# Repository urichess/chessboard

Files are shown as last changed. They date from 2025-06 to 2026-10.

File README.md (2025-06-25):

# chessboard

tests of chessboard using arduino + zephyr

Start up

1. install zephyr

https://docs.zephyrproject.org/latest/develop/getting_started/index.html

2. install Stm32CubeIDE & Stm32CubeProgrammer

3. clone this repo

4. (optionl) configure cubeide
https://docs.zephyrproject.org/latest/develop/tools/stm32cubeide.html

Interesting links

Proyectos y tecnologías clave que te pueden ayudar
1. lichess-bot

https://github.com/lichess-bot-devs/lichess-bot

Un bot que se conecta a la API de Lichess y puede jugar partidas automáticamente.

Puedes modificarlo para que, en lugar de usar un motor de ajedrez, se comunique con tu hardware.

Es ideal como punto de partida para jugar partidas en Lichess a través de tu propio programa.

2. PySerial

https://pyserial.readthedocs.io/en/latest/pyserial.html#overview
Para comunicarte con tu tablero por USB (si usas un puerto serie virtual tipo /dev/ttyUSB0).

Puedes leer movimientos desde tu tablero y enviarle información como el movimiento del oponente.

3. Python-Chess
https://python-chess.readthedocs.io/en/latest/#
Excelente librería para manejar lógica de ajedrez (validar jugadas, FENs, PGNs).

Puedes usarla para comparar el estado del juego local con el de Lichess y traducir movimientos.

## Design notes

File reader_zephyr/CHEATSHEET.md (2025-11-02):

#INIT ENV
. ./scripts/activate

#COMPILE

./scripts/build_all.sh [-clean]

#ZEPHYR COMMANDS TO COMPILE

west build -p always -b arduino_uno_r4_wifi

west build -p always -b nucleo_g474re
west build -p auto -b nucleo_g474re
west build -p always -b nucleo_g474re -t dt

#CONFIG

west build -b chessboard_l431_v1 -t menuconfig app

#UTILS
west boards

#UPGRADING

cd  $ZEPHYR_BASE
git pull
west update
west packages pip --install

python -m serial.tools.miniterm /dev/ttyACM0 115200
west build -b chessboard_l431_v1  -d build/mcuboot/ -p auto  bootloader/mcuboot/boot/zephyr/ -t menuconfig --extra-conf /home/elotro/work/chessApps/chessboard/reader_zephyr/bootloader/config_overrides.conf

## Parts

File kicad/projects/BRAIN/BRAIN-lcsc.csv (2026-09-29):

Reference | Value | Qty | MP | LCSC p/n
J1 | USB_C_Receptacle_USB2.0_16P | 1 | XKB Connection U262-161N-4BS165 | C2879826
J15 | CONN_2x03 | 1 | XFCN PZ254V-12-6P | C492421
J11 | CONN_1x14 | 1 | X6511FV-14-C85D32 | C2883731
D3 | TVS3V3L4U | 1 | TVS3V3L4U | C28642315
SW1,SW2,SW3 | TL3342F450QG | 3 | TL3342F450QG | C318884
D8,D9 | SS14 | 2 | SS14-E3/61T | C47460
R2,R3,R4,R6,R8,R9,R12 | 5.1k | 7 | RC0805FR-075K1L | C84375
R15 | 47k | 1 | RC0805FR-0747KL | C126351
R1,R13,R14 | 10k | 3 | RC0805FR-0710KL | C84376
R7 | 1k | 1 | RC0805FR-071KL | C95781
J16 | CONN_2x04 | 1 | PZ254V-12-8P | C492421
J18 | Free | 1 | PZ254V-11-04P | C2691448
J14 | UART | 1 | PZ254V-11-04P | C2691448
D7 | PESD5V0L2BT | 1 | PESD5V0L2BT,215 | C12324
Y1 | NX3215SA-32.768KHZ-EXS00A-MU00525 | 1 | NX3215SA 32.768KHZ EXS00A-MU00525 | C528987 | C5142784
D1,D2,D6 | LED_GREEN | 3 | L170B-YGC-GA-TR | C84260
D5 | LED_ORANGE | 1 | L170B-QOC-TR | C965817
D4 | LED_RED | 1 | L170B-EC-TR | C84256
J12 | CONN_2x02 | 1 | JST RF-H042TD-1190(LF)(SN) | C160338
U7 | ESP32-S3-MINI-1-N8 | 1 | ESP32-S3-MINI-1-N8 | C2913206
J9 | CONN_01x02 | 1 | DW254R-11-02-85 | C2935896
C7,C10 | 4.7pF | 2 | CL21C470JBANNNC | C1820
C4 | 22pF | 1 | CL21C220JBANNNC | C1804
C1,C5,C6,C9,C13,C14 | 100nF | 6 | CL21B104KBCNNNC | C1711
C8,C11,C12,C15,C16 | 1uF | 5 | CL21A105KOFNNNE | C24123 | FALTA
J2,J4 | Conn_ARM_JTAG_SWD_10 | 2 | BD125-16-A-0305-0580-L-B | C17283499 | FALTA
Q2 | BC847 | 1 | BC847B,215 | C57668
J10 | CONN_2x1 | 1 | B2B-EH-A(LF)(SN) | C160262
U1,U3 | AP2112K-3.3 | 2 | AP2112K-3.3TRG1 | C23380830
C2,C3 | 3.9pF | 2 | 0805CG3R9C500NT | C1813
J13 | UART TEST | 1 | 22284020 | C234182
R16,R17,R18,R19 | 100 | 4 |  | C17408
J8 | Conn_02x11_Odd_Even | 1 |  |  | FALTA
J3,J5,J6,J7 | Conn_01x07 | 4 |  |  | FALTA
C17,C18,C19,C20 | 1uF | 4 |  | C28323
REEMPLAZADO
U2 | STM32L431CCTx | 1 | STM32L431CCTx | C486681
TUOMO
NO COMPRADO
LS1 | CMT-1203-SMT | 1 | CMT-1203-SMT-TR |  | FALTA
U4 | 24LC512 | 1 | 24LC512T-I/SN | C52088 | FALTA

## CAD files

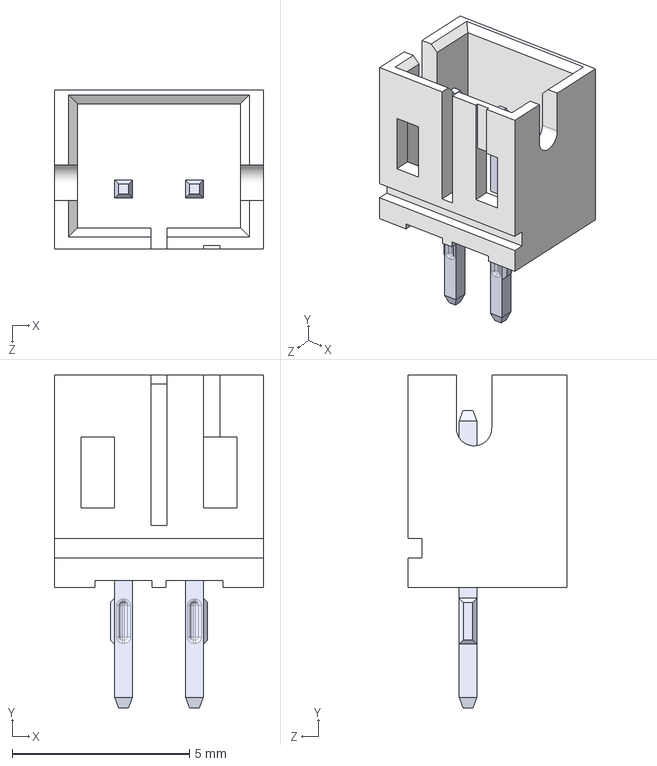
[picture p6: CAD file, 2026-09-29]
kicad/MY_PARTS/B2B-PH-K-S_LF__SN_/B2B-PH-K-S_LF__SN_.step
5.90 x 9.40 x 4.50 mm

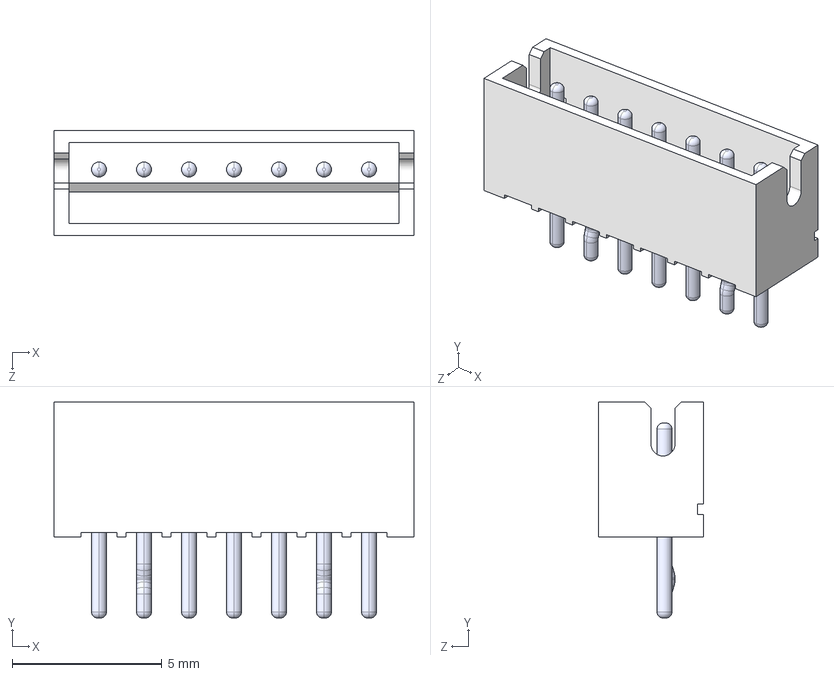
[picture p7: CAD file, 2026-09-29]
kicad/MY_PARTS/B7B-ZR_LF__SN_/B7B-ZR_LF__SN_.step
12.0 x 7.20 x 3.50 mm
BxB-ZR_7
pin_straight x 5
pin_Bent x 2

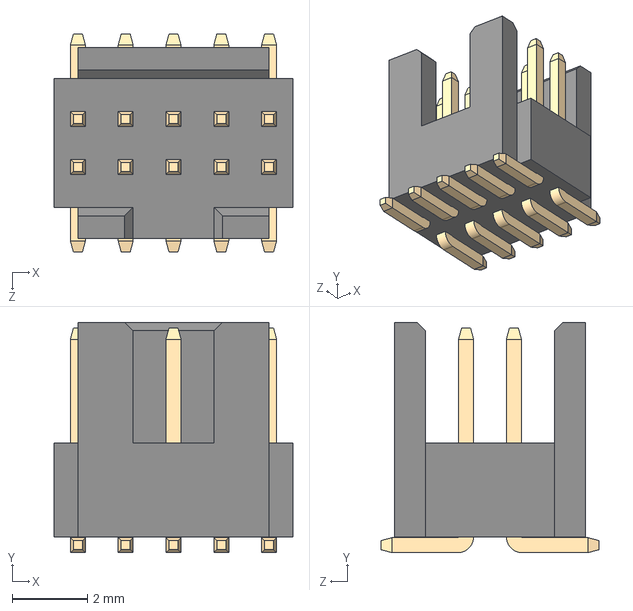
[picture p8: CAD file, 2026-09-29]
kicad/MY_PARTS/BD125-10-A-0305-0580-L-B/BD125-10-A-0305-0580-L-B.step
6.35 x 6.12 x 5.80 mm

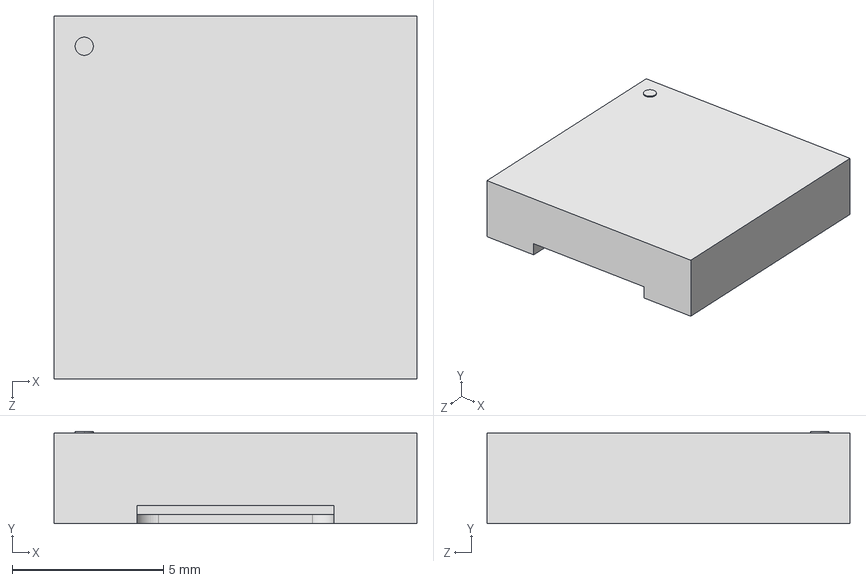
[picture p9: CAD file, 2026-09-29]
kicad/MY_PARTS/CMT-1203-SMT/CMT-1203-SMT.step
12.0 x 3.05 x 12.0 mm

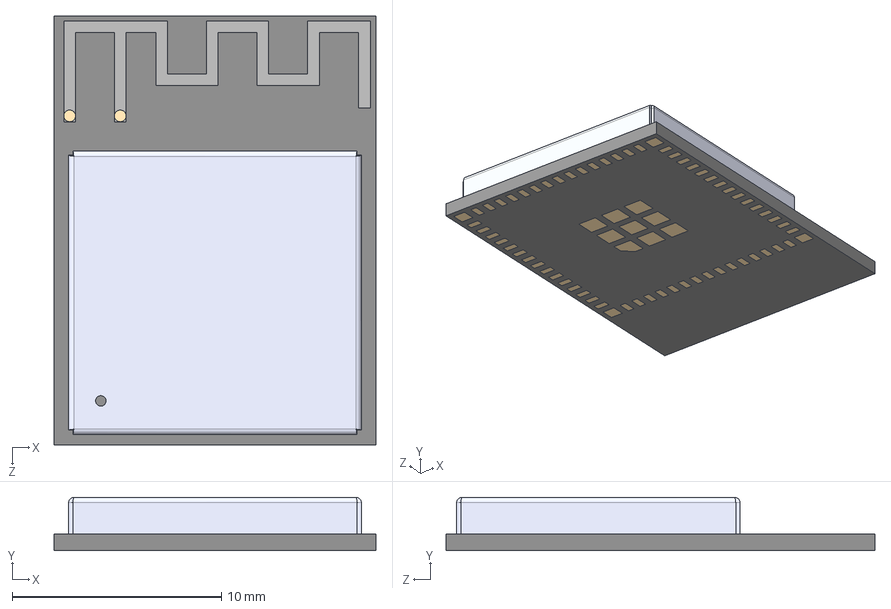
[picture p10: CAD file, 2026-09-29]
kicad/MY_PARTS/ESP32-S3-MINI-1-N8/ESP32-S3-MINI-1-N8.step
15.4 x 2.55 x 20.5 mm

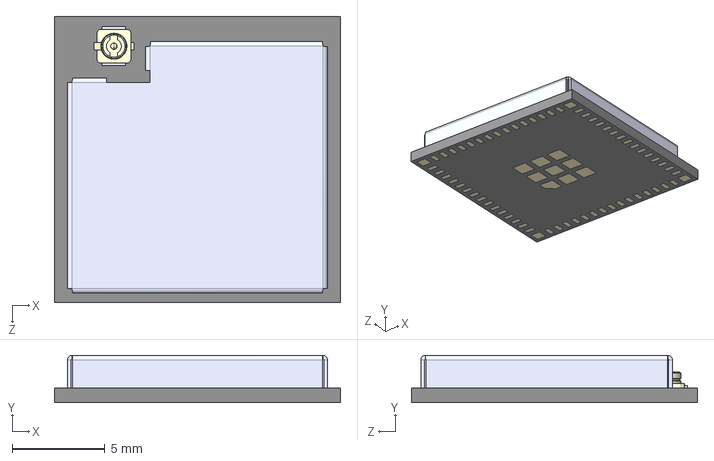
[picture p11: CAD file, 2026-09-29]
kicad/MY_PARTS/ESP32-S3-MINI-1U-N8/ESP32-S3-MINI-1U-N8.step
15.4 x 2.55 x 15.4 mm
ESP32-S3-MINI-1U-N8_ESP32-C3-MINI-1-N4
antenna jack

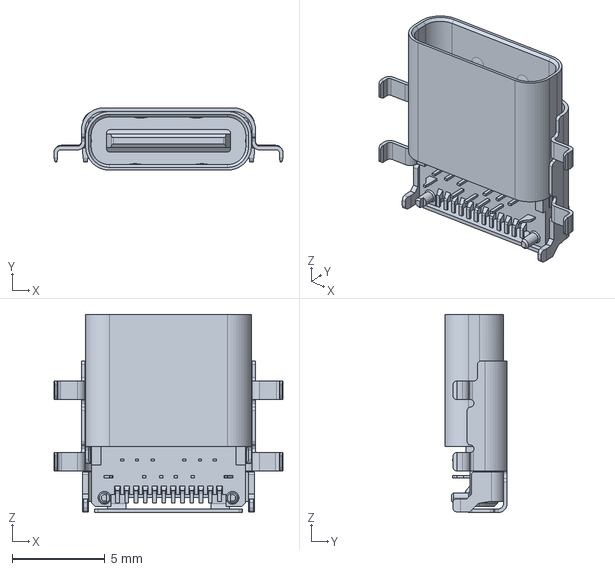
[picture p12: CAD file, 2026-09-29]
kicad/MY_PARTS/2129691-2/2129691-2.step
12.4 x 3.36 x 10.7 mm

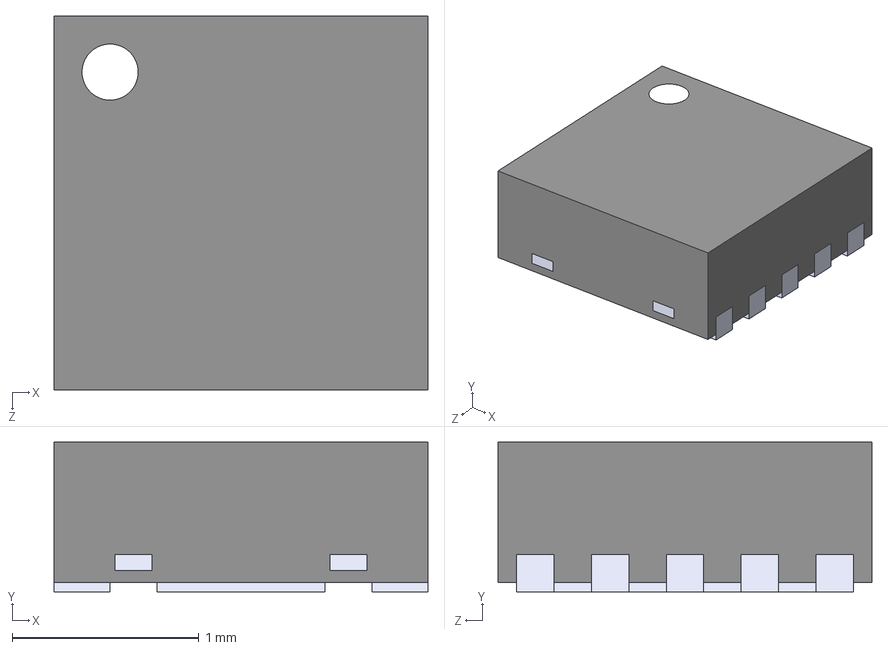
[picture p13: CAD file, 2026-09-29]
kicad/MY_PARTS/BQ24040DSQR/BQ24040DSQR.step
2.00 x 0.8 x 2.00 mm

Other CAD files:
CAD/FullBoardSQ5/full_board_sq5.FCStd

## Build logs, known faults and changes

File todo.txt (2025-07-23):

PROBLEMS

hw
----

black/white detection. Improves captures.

sw
----

handling promotion, now it's always a queen
support moving opponent piece before player on turn, when capturing

PROTOS UPGRADE

wifi/bluetooth with esp32

- chesscomputer soldering.
 a. test esp32.
 b. validate stm32 debug jtag
 c. validate esp32 debug jtag
 d. see other features are also working ok. reading sensors + calibrations stability

- new board x5
 - including esp32 for extra option with bluetooth serial wireless? or perhaps better working ONLY with usb?
 - autonomous with esp32? android?

NEW FUNCTIONALITIES

- UI
- play a friend on lichess, both OTB
- sparring from a study
- lichess authentication instead of token?

- Android App?

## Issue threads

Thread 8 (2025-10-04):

Support board inversion

eltiempopaso, 2025-10-04:
To enable testing with board upside down, ready for reworks

Closed 2025-10-04.

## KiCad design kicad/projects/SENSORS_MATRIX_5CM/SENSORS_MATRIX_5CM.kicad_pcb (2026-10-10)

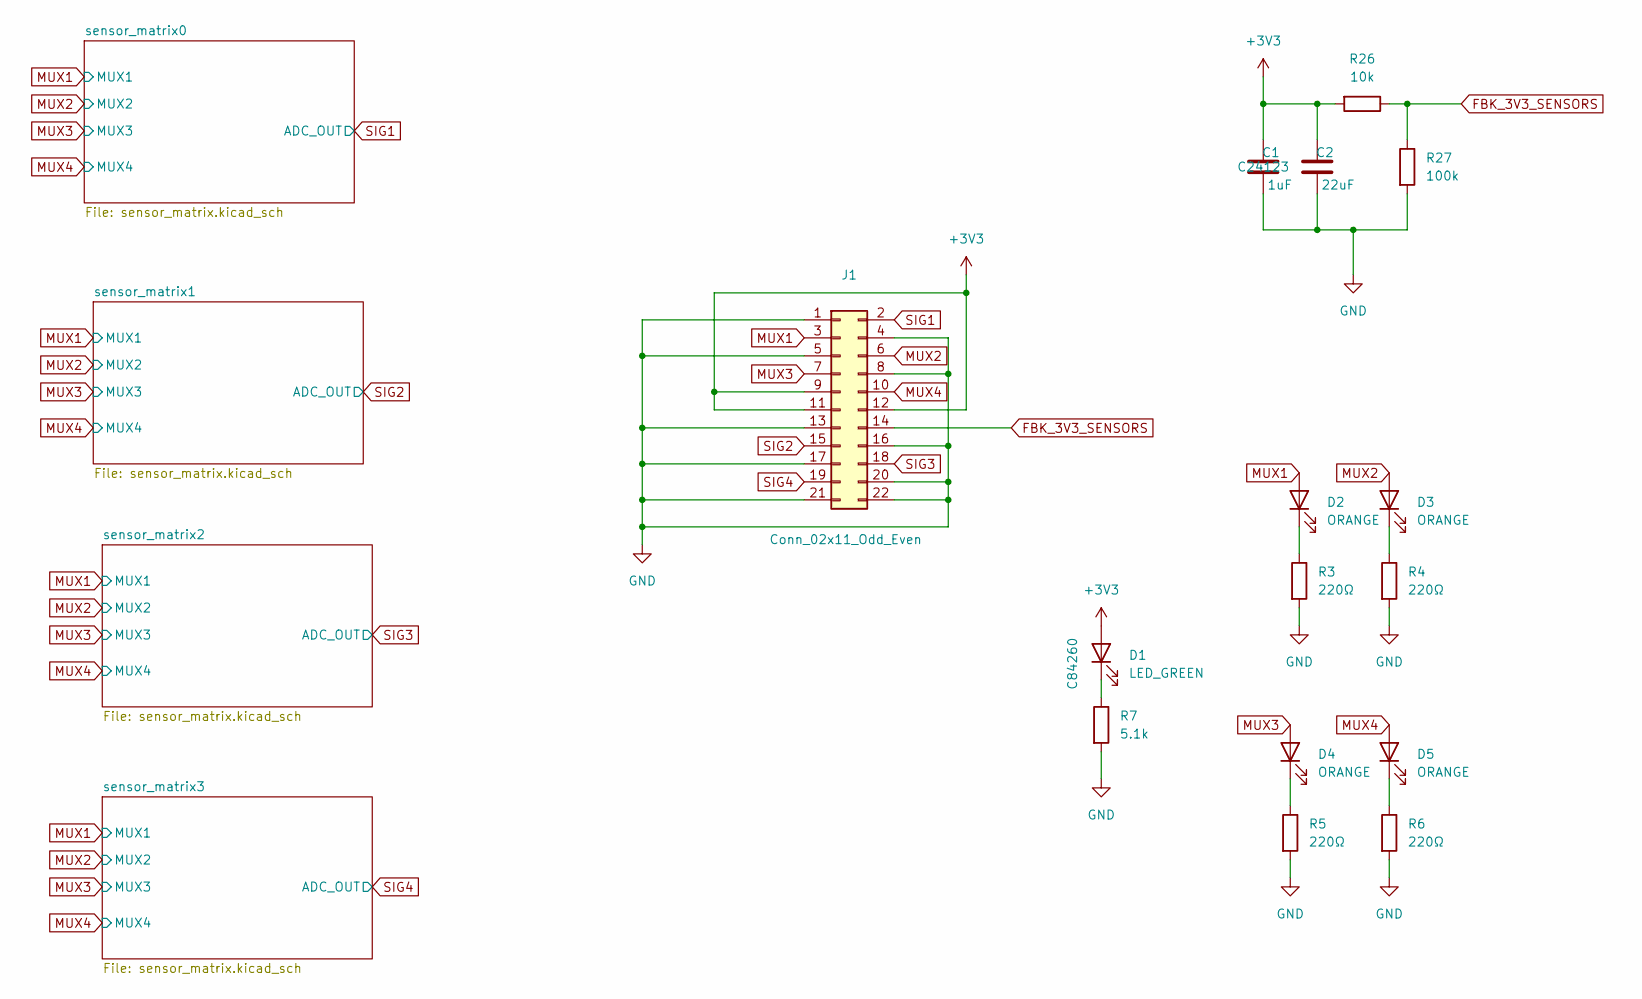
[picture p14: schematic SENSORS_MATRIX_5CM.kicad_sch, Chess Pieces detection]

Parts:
C1: 1uF; C_0805_2012Metric_Pad1.18x1.45mm_HandSolder; LCSC p/n C24123
C2: 22uF; C_0805_2012Metric_Pad1.18x1.45mm_HandSolder
D1: LED_GREEN; LED_0805_2012Metric_Pad1.15x1.40mm_HandSolder; LCSC p/n C84260
D2, D3, D4, D5: ORANGE; LED_0805_2012Metric_Pad1.15x1.40mm_HandSolder
J1: Conn_02x11_Odd_Even; PinSocket_2x11_P2.54mm_Horizontal
R3, R4, R5, R6: 220Ω; R_0805_2012Metric_Pad1.20x1.40mm_HandSolder
R7: 5.1k; R_0805_2012Metric_Pad1.20x1.40mm_HandSolder; LCSC p/n C84375
R26: 10k; R_0805_2012Metric_Pad1.20x1.40mm_HandSolder; LCSC p/n C84376
R27: 100k; R_0805_2012Metric_Pad1.20x1.40mm_HandSolder

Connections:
+3V3: C1.1, C2.1, D1.2 (A), J1.9, J1.11, J1.12, R26.2; also elsewhere on the board
FBK_3V3_SENSORS: J1.14, R26.1, R27.1
GND: C1.2, C2.2, J1.1, J1.4, J1.5, J1.8, J1.13, J1.16, J1.17, J1.20, J1.21, J1.22, R3.2, R4.2, R5.2, R6.2, R7.2, R27.2; also elsewhere on the board
MUX1: D2.2 (A), J1.3; also elsewhere on the board
MUX2: D3.2 (A), J1.6; also elsewhere on the board
MUX3: D4.2 (A), J1.7; also elsewhere on the board
MUX4: D5.2 (A), J1.10; also elsewhere on the board
unnamed: D1.1 (K), R7.1
unnamed: D2.1 (K), R3.1
unnamed: D3.1 (K), R4.1
unnamed: D4.1 (K), R5.1
unnamed: D5.1 (K), R6.1
SIG1: J1.2; also elsewhere on the board
SIG2: J1.15; also elsewhere on the board
SIG3: J1.18; also elsewhere on the board
SIG4: J1.19; also elsewhere on the board

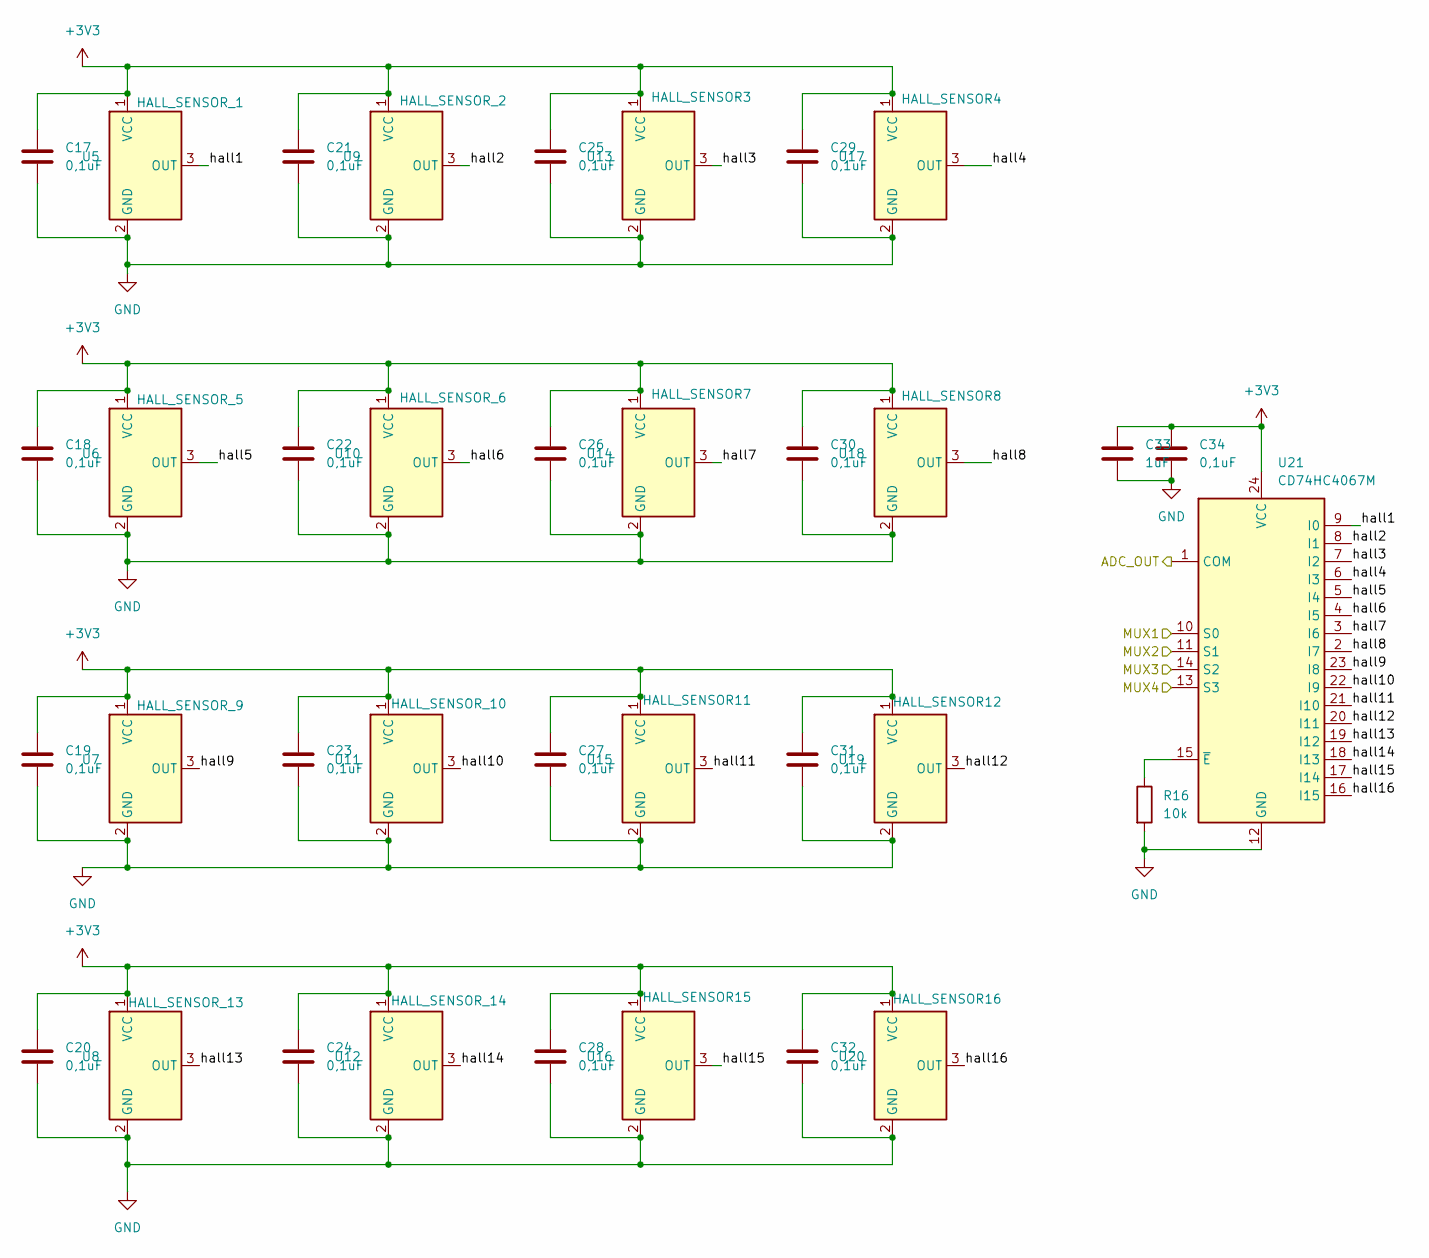
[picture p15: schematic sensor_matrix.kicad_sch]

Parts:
C17, C18, C19, C20, C21, C22, C23, C24, C25, C26, C27, C28, C29, C30, C31, C32, C34: 0,1uF; C_0805_2012Metric_Pad1.18x1.45mm_HandSolder
C33: 1uF; C_0805_2012Metric_Pad1.18x1.45mm_HandSolder; LCSC p/n C24123
R16: 10k; R_0805_2012Metric_Pad1.20x1.40mm_HandSolder; LCSC p/n C84376
U5: HALL_SENSOR_1; SOT-23_Handsoldering; LCSC p/n C2864477
U6: HALL_SENSOR_5; SOT-23_Handsoldering; LCSC p/n C2864477
U7: HALL_SENSOR_9; SOT-23_Handsoldering; LCSC p/n C2864477
U8: HALL_SENSOR_13; SOT-23_Handsoldering; LCSC p/n C2864477
U9: HALL_SENSOR_2; SOT-23_Handsoldering; LCSC p/n C2864477
U10: HALL_SENSOR_6; SOT-23_Handsoldering; LCSC p/n C2864477
U11: HALL_SENSOR_10; SOT-23_Handsoldering; LCSC p/n C2864477
U12: HALL_SENSOR_14; SOT-23_Handsoldering; LCSC p/n C2864477
U13: HALL_SENSOR3; SOT-23_Handsoldering; LCSC p/n C2864477
U14: HALL_SENSOR7; SOT-23_Handsoldering; LCSC p/n C2864477
U15: HALL_SENSOR11; SOT-23_Handsoldering; LCSC p/n C2864477
U16: HALL_SENSOR15; SOT-23_Handsoldering; LCSC p/n C2864477
U17: HALL_SENSOR4; SOT-23_Handsoldering; LCSC p/n C2864477
U18: HALL_SENSOR8; SOT-23_Handsoldering; LCSC p/n C2864477
U19: HALL_SENSOR12; SOT-23_Handsoldering; LCSC p/n C2864477
U20: HALL_SENSOR16; SOT-23_Handsoldering; LCSC p/n C2864477
U21: CD74HC4067M; SOIC-24W_7.5x15.4mm_P1.27mm; LCSC p/n C496123

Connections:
+3V3: C17.1, C18.1, C19.1, C20.1, C21.1, C22.1, C23.1, C24.1, C25.1, C26.1, C27.1, C28.1, C29.1, C30.1, C31.1, C32.1, C33.1, C34.1, U5.1 (VCC), U6.1 (VCC), U7.1 (VCC), U8.1 (VCC), U9.1 (VCC), U10.1 (VCC), U11.1 (VCC), U12.1 (VCC), U13.1 (VCC), U14.1 (VCC), U15.1 (VCC), U16.1 (VCC), U17.1 (VCC), U18.1 (VCC), U19.1 (VCC), U20.1 (VCC), U21.24 (VCC); also elsewhere on the board
/sensor_matrix0/hall1: U5.3 (OUT), U21.9 (I0)
/sensor_matrix0/hall2: U9.3 (OUT), U21.8 (I1)
/sensor_matrix0/hall3: U13.3 (OUT), U21.7 (I2)
/sensor_matrix0/hall4: U17.3 (OUT), U21.6 (I3)
/sensor_matrix0/hall5: U6.3 (OUT), U21.5 (I4)
/sensor_matrix0/hall6: U10.3 (OUT), U21.4 (I5)
/sensor_matrix0/hall7: U14.3 (OUT), U21.3 (I6)
/sensor_matrix0/hall8: U18.3 (OUT), U21.2 (I7)
/sensor_matrix0/hall9: U7.3 (OUT), U21.23 (I8)
/sensor_matrix0/hall10: U11.3 (OUT), U21.22 (I9)
/sensor_matrix0/hall11: U15.3 (OUT), U21.21 (I10)
/sensor_matrix0/hall12: U19.3 (OUT), U21.20 (I11)
/sensor_matrix0/hall13: U8.3 (OUT), U21.19 (I12)
/sensor_matrix0/hall14: U12.3 (OUT), U21.18 (I13)
/sensor_matrix0/hall15: U16.3 (OUT), U21.17 (I14)
/sensor_matrix0/hall16: U20.3 (OUT), U21.16 (I15)
GND: C17.2, C18.2, C19.2, C20.2, C21.2, C22.2, C23.2, C24.2, C25.2, C26.2, C27.2, C28.2, C29.2, C30.2, C31.2, C32.2, C33.2, C34.2, R16.2, U5.2 (GND), U6.2 (GND), U7.2 (GND), U8.2 (GND), U9.2 (GND), U10.2 (GND), U11.2 (GND), U12.2 (GND), U13.2 (GND), U14.2 (GND), U15.2 (GND), U16.2 (GND), U17.2 (GND), U18.2 (GND), U19.2 (GND), U20.2 (GND), U21.12 (GND); also elsewhere on the board
MUX1: U21.10 (S0); also elsewhere on the board
MUX2: U21.11 (S1); also elsewhere on the board
MUX3: U21.14 (S2); also elsewhere on the board
MUX4: U21.13 (S3); also elsewhere on the board
unnamed: R16.1, U21.15 (~E)
SIG1: U21.1 (COM); also elsewhere on the board

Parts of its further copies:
C35, C36, C37, C38, C39, C40, C41, C42, C43, C44, C45, C46, C47, C48, C49, C50, C52, C53, C54, C55, C56, C57, C58, C59, C60, C61, C62, C63, C64, C65, C66, C67, C68, C70, C71, C72, C73, C74, C75, C76, C77, C78, C79, C80, C81, C82, C83, C84, C85, C86, C88: 0,1uF; C_0805_2012Metric_Pad1.18x1.45mm_HandSolder
C51, C69, C87: 1uF; C_0805_2012Metric_Pad1.18x1.45mm_HandSolder; LCSC p/n C24123
U22, U39, U56: HALL_SENSOR_1; SOT-23_Handsoldering; LCSC p/n C2864477
U23, U40, U57: HALL_SENSOR_5; SOT-23_Handsoldering; LCSC p/n C2864477
U24, U41, U58: HALL_SENSOR_9; SOT-23_Handsoldering; LCSC p/n C2864477
U25, U42, U59: HALL_SENSOR_13; SOT-23_Handsoldering; LCSC p/n C2864477
U26, U43, U60: HALL_SENSOR_2; SOT-23_Handsoldering; LCSC p/n C2864477
U27, U44, U61: HALL_SENSOR_6; SOT-23_Handsoldering; LCSC p/n C2864477
U28, U45, U62: HALL_SENSOR_10; SOT-23_Handsoldering; LCSC p/n C2864477
U29, U46, U63: HALL_SENSOR_14; SOT-23_Handsoldering; LCSC p/n C2864477
U30, U47, U64: HALL_SENSOR3; SOT-23_Handsoldering; LCSC p/n C2864477
U31, U48, U65: HALL_SENSOR7; SOT-23_Handsoldering; LCSC p/n C2864477
U32, U49, U66: HALL_SENSOR11; SOT-23_Handsoldering; LCSC p/n C2864477
U33, U50, U67: HALL_SENSOR15; SOT-23_Handsoldering; LCSC p/n C2864477
U34, U51, U68: HALL_SENSOR4; SOT-23_Handsoldering; LCSC p/n C2864477
U35, U52, U69: HALL_SENSOR8; SOT-23_Handsoldering; LCSC p/n C2864477
U36, U53, U70: HALL_SENSOR12; SOT-23_Handsoldering; LCSC p/n C2864477
U37, U54, U71: HALL_SENSOR16; SOT-23_Handsoldering; LCSC p/n C2864477
U38, U55, U72: CD74HC4067M; SOIC-24W_7.5x15.4mm_P1.27mm; LCSC p/n C496123

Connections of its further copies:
+3V3: C35.1, C36.1, C37.1, C38.1, C39.1, C40.1, C41.1, C42.1, C43.1, C44.1, C45.1, C46.1, C47.1, C48.1, C49.1, C50.1, C51.1, C52.1, C53.1, C54.1, C55.1, C56.1, C57.1, C58.1, C59.1, C60.1, C61.1, C62.1, C63.1, C64.1, C65.1, C66.1, C67.1, C68.1, C69.1, C70.1, C71.1, C72.1, C73.1, C74.1, C75.1, C76.1, C77.1, C78.1, C79.1, C80.1, C81.1, C82.1, C83.1, C84.1, C85.1, C86.1, C87.1, C88.1, U22.1 (VCC), U23.1 (VCC), U24.1 (VCC), U25.1 (VCC), U26.1 (VCC), U27.1 (VCC), U28.1 (VCC), U29.1 (VCC), U30.1 (VCC), U31.1 (VCC), U32.1 (VCC), U33.1 (VCC), U34.1 (VCC), U35.1 (VCC), U36.1 (VCC), U37.1 (VCC), U38.24 (VCC), U39.1 (VCC), U40.1 (VCC), U41.1 (VCC), U42.1 (VCC), U43.1 (VCC), U44.1 (VCC), U45.1 (VCC), U46.1 (VCC), U47.1 (VCC), U48.1 (VCC), U49.1 (VCC), U50.1 (VCC), U51.1 (VCC), U52.1 (VCC), U53.1 (VCC), U54.1 (VCC), U55.24 (VCC), U56.1 (VCC), U57.1 (VCC), U58.1 (VCC), U59.1 (VCC), U60.1 (VCC), U61.1 (VCC), U62.1 (VCC), U63.1 (VCC), U64.1 (VCC), U65.1 (VCC), U66.1 (VCC), U67.1 (VCC), U68.1 (VCC), U69.1 (VCC), U70.1 (VCC), U71.1 (VCC), U72.24 (VCC); also elsewhere on the board
/sensor_matrix1/hall1: U22.3 (OUT), U38.9 (I0)
/sensor_matrix1/hall2: U26.3 (OUT), U38.8 (I1)
/sensor_matrix1/hall3: U30.3 (OUT), U38.7 (I2)
/sensor_matrix1/hall4: U34.3 (OUT), U38.6 (I3)
/sensor_matrix1/hall5: U23.3 (OUT), U38.5 (I4)
/sensor_matrix1/hall6: U27.3 (OUT), U38.4 (I5)
/sensor_matrix1/hall7: U31.3 (OUT), U38.3 (I6)
/sensor_matrix1/hall8: U35.3 (OUT), U38.2 (I7)
/sensor_matrix1/hall9: U24.3 (OUT), U38.23 (I8)
/sensor_matrix1/hall10: U28.3 (OUT), U38.22 (I9)
/sensor_matrix1/hall11: U32.3 (OUT), U38.21 (I10)
/sensor_matrix1/hall12: U36.3 (OUT), U38.20 (I11)
/sensor_matrix1/hall13: U25.3 (OUT), U38.19 (I12)
/sensor_matrix1/hall14: U29.3 (OUT), U38.18 (I13)
/sensor_matrix1/hall15: U33.3 (OUT), U38.17 (I14)
/sensor_matrix1/hall16: U37.3 (OUT), U38.16 (I15)
/sensor_matrix2/hall1: U39.3 (OUT), U55.9 (I0)
/sensor_matrix2/hall2: U43.3 (OUT), U55.8 (I1)
/sensor_matrix2/hall3: U47.3 (OUT), U55.7 (I2)
/sensor_matrix2/hall4: U51.3 (OUT), U55.6 (I3)
/sensor_matrix2/hall5: U40.3 (OUT), U55.5 (I4)
/sensor_matrix2/hall6: U44.3 (OUT), U55.4 (I5)
/sensor_matrix2/hall7: U48.3 (OUT), U55.3 (I6)
/sensor_matrix2/hall8: U52.3 (OUT), U55.2 (I7)
/sensor_matrix2/hall9: U41.3 (OUT), U55.23 (I8)
/sensor_matrix2/hall10: U45.3 (OUT), U55.22 (I9)
/sensor_matrix2/hall11: U49.3 (OUT), U55.21 (I10)
/sensor_matrix2/hall12: U53.3 (OUT), U55.20 (I11)
/sensor_matrix2/hall13: U42.3 (OUT), U55.19 (I12)
/sensor_matrix2/hall14: U46.3 (OUT), U55.18 (I13)
/sensor_matrix2/hall15: U50.3 (OUT), U55.17 (I14)
/sensor_matrix2/hall16: U54.3 (OUT), U55.16 (I15)
/sensor_matrix3/hall1: U56.3 (OUT), U72.9 (I0)
/sensor_matrix3/hall2: U60.3 (OUT), U72.8 (I1)
/sensor_matrix3/hall3: U64.3 (OUT), U72.7 (I2)
/sensor_matrix3/hall4: U68.3 (OUT), U72.6 (I3)
/sensor_matrix3/hall5: U57.3 (OUT), U72.5 (I4)
/sensor_matrix3/hall6: U61.3 (OUT), U72.4 (I5)
/sensor_matrix3/hall7: U65.3 (OUT), U72.3 (I6)
/sensor_matrix3/hall8: U69.3 (OUT), U72.2 (I7)
/sensor_matrix3/hall9: U58.3 (OUT), U72.23 (I8)
/sensor_matrix3/hall10: U62.3 (OUT), U72.22 (I9)
/sensor_matrix3/hall11: U66.3 (OUT), U72.21 (I10)
/sensor_matrix3/hall12: U70.3 (OUT), U72.20 (I11)
/sensor_matrix3/hall13: U59.3 (OUT), U72.19 (I12)
/sensor_matrix3/hall14: U63.3 (OUT), U72.18 (I13)
/sensor_matrix3/hall15: U67.3 (OUT), U72.17 (I14)
/sensor_matrix3/hall16: U71.3 (OUT), U72.16 (I15)
GND: C35.2, C36.2, C37.2, C38.2, C39.2, C40.2, C41.2, C42.2, C43.2, C44.2, C45.2, C46.2, C47.2, C48.2, C49.2, C50.2, C51.2, C52.2, C53.2, C54.2, C55.2, C56.2, C57.2, C58.2, C59.2, C60.2, C61.2, C62.2, C63.2, C64.2, C65.2, C66.2, C67.2, C68.2, C69.2, C70.2, C71.2, C72.2, C73.2, C74.2, C75.2, C76.2, C77.2, C78.2, C79.2, C80.2, C81.2, C82.2, C83.2, C84.2, C85.2, C86.2, C87.2, C88.2, U22.2 (GND), U23.2 (GND), U24.2 (GND), U25.2 (GND), U26.2 (GND), U27.2 (GND), U28.2 (GND), U29.2 (GND), U30.2 (GND), U31.2 (GND), U32.2 (GND), U33.2 (GND), U34.2 (GND), U35.2 (GND), U36.2 (GND), U37.2 (GND), U38.12 (GND), U39.2 (GND), U40.2 (GND), U41.2 (GND), U42.2 (GND), U43.2 (GND), U44.2 (GND), U45.2 (GND), U46.2 (GND), U47.2 (GND), U48.2 (GND), U49.2 (GND), U50.2 (GND), U51.2 (GND), U52.2 (GND), U53.2 (GND), U54.2 (GND), U55.12 (GND), U56.2 (GND), U57.2 (GND), U58.2 (GND), U59.2 (GND), U60.2 (GND), U61.2 (GND), U62.2 (GND), U63.2 (GND), U64.2 (GND), U65.2 (GND), U66.2 (GND), U67.2 (GND), U68.2 (GND), U69.2 (GND), U70.2 (GND), U71.2 (GND), U72.12 (GND); also elsewhere on the board
MUX1: U38.10 (S0), U55.10 (S0), U72.10 (S0); also elsewhere on the board
MUX2: U38.11 (S1), U55.11 (S1), U72.11 (S1); also elsewhere on the board
MUX3: U38.14 (S2), U55.14 (S2), U72.14 (S2); also elsewhere on the board
MUX4: U38.13 (S3), U55.13 (S3), U72.13 (S3); also elsewhere on the board
unnamed 77: U38.15 (~E); also elsewhere on the board
unnamed 78: U55.15 (~E); also elsewhere on the board
unnamed 79: U72.15 (~E); also elsewhere on the board
SIG2: U38.1 (COM); also elsewhere on the board
SIG3: U55.1 (COM); also elsewhere on the board
SIG4: U72.1 (COM); also elsewhere on the board

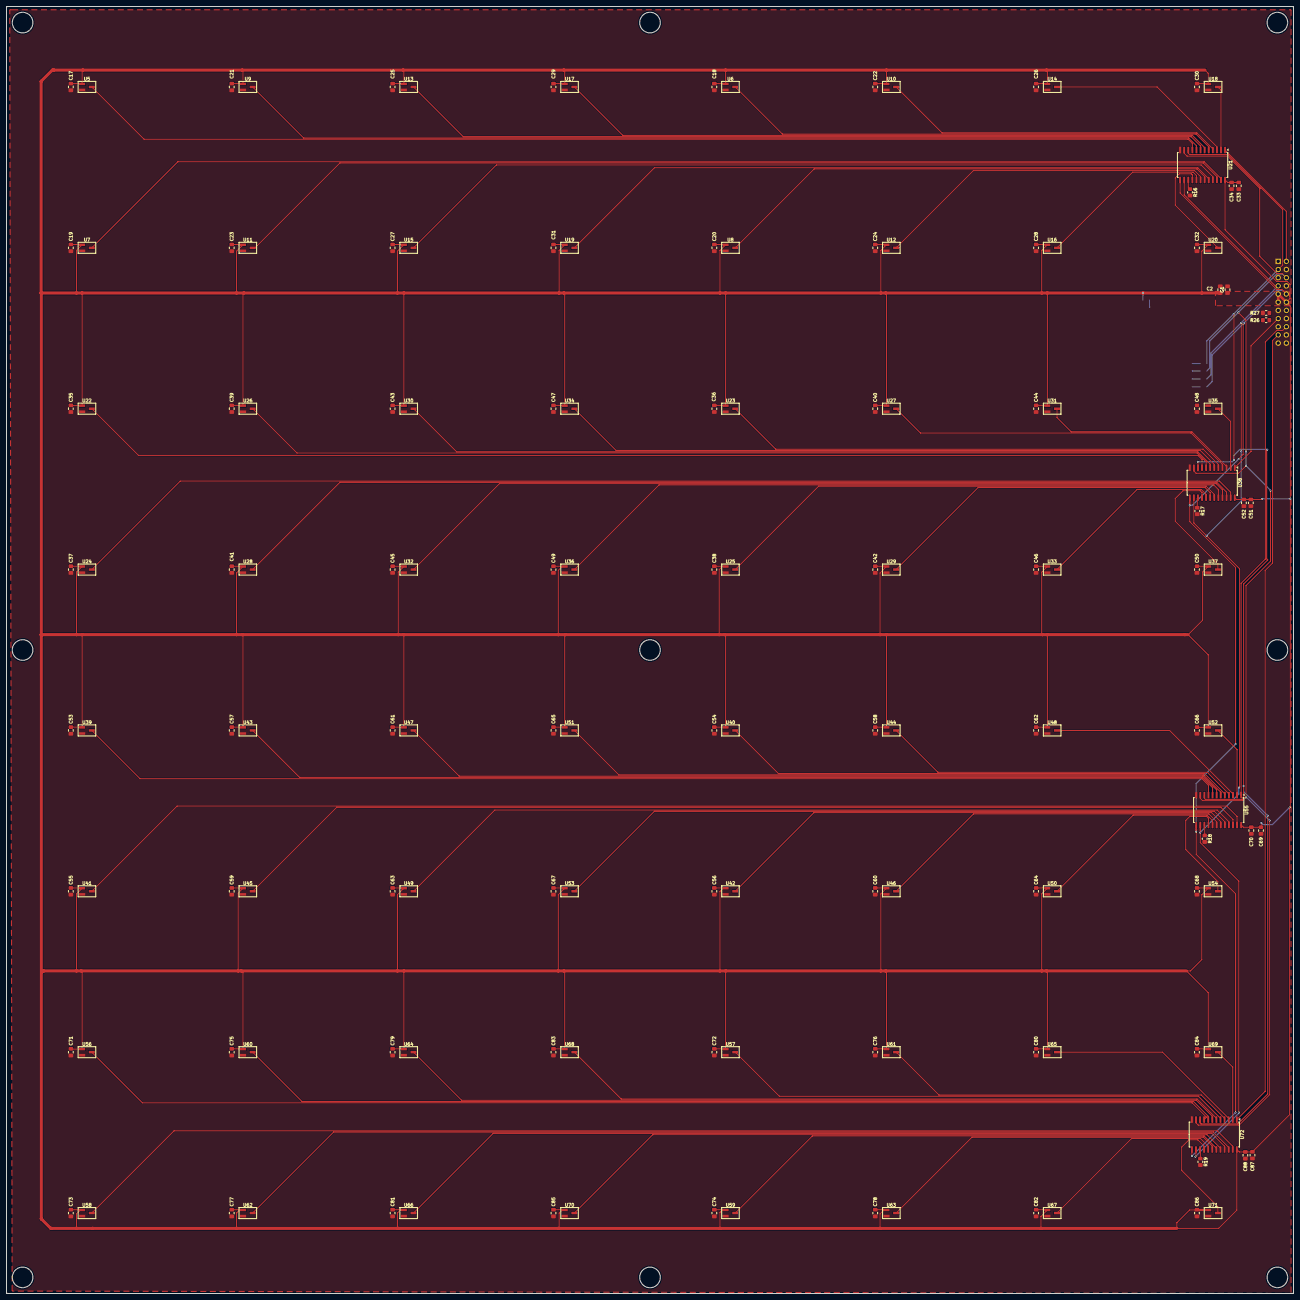
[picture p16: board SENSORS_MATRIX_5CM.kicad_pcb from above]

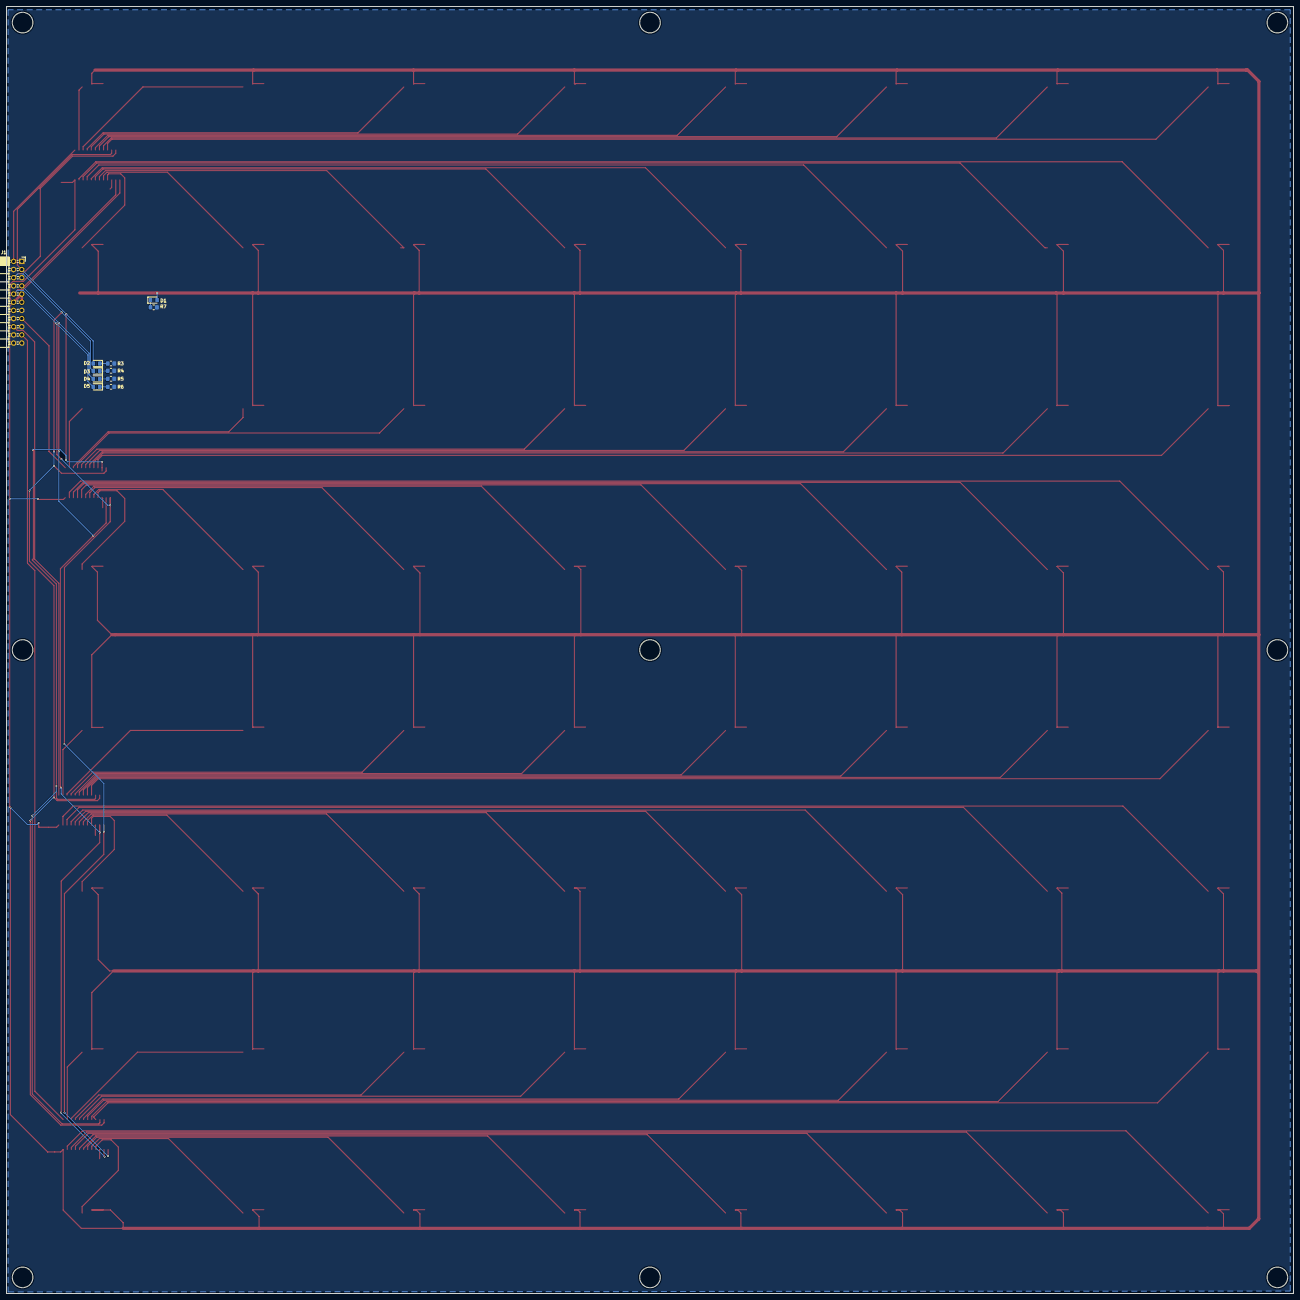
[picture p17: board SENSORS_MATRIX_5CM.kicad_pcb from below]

Board: 2 copper layers, 400.0 x 400.0 mm, 159 parts (11 on the bottom side), 84 nets.

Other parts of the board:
R17, R18, R19: 10K; R_0805_2012Metric_Pad1.20x1.40mm_HandSolder

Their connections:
GND: R17.2, R18.2, R19.2; also elsewhere on the board
unnamed 77: R17.1; also elsewhere on the board
unnamed 78: R18.1; also elsewhere on the board
unnamed 79: R19.1; also elsewhere on the board

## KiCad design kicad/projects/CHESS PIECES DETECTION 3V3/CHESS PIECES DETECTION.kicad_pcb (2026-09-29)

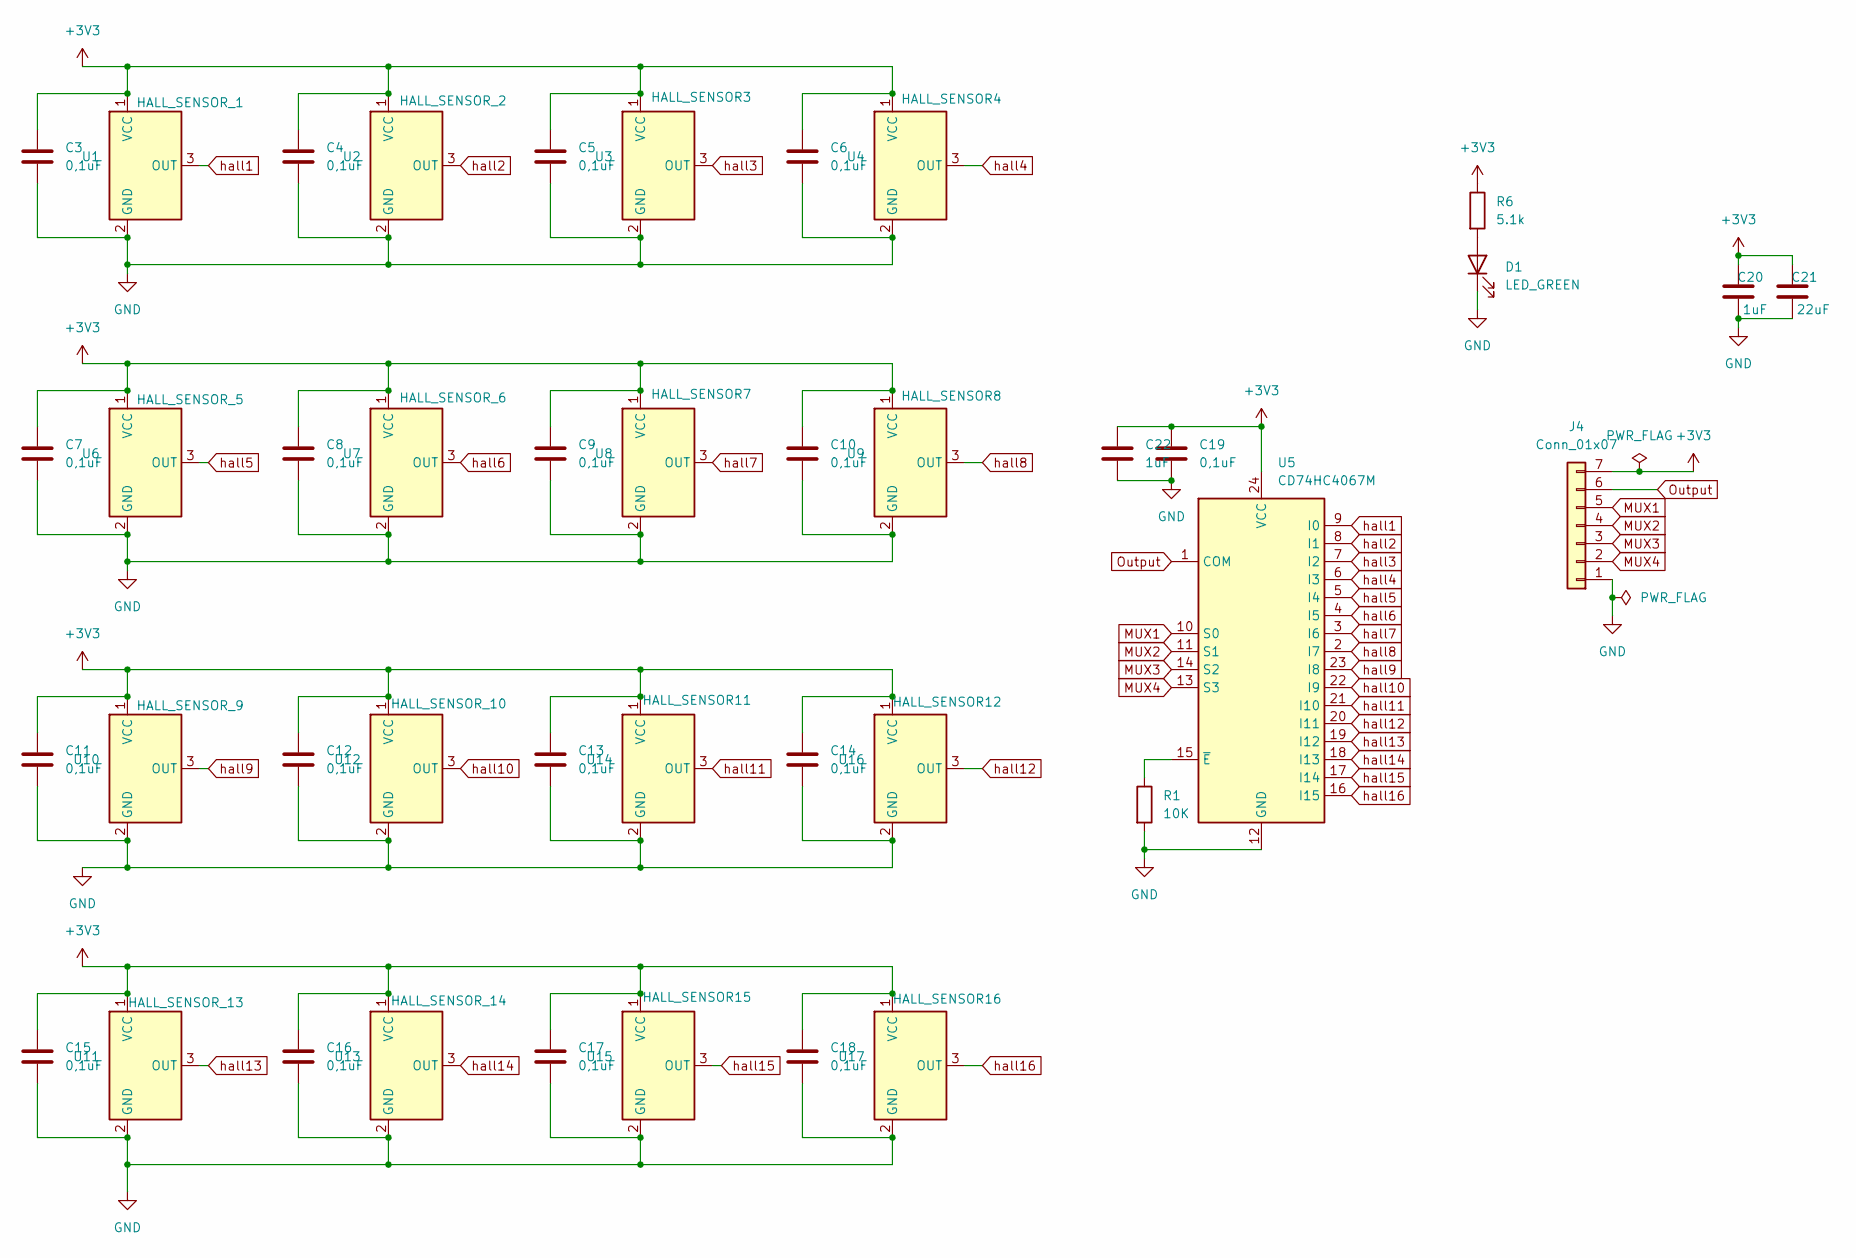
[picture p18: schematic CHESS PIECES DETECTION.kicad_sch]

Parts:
C3, C4, C5, C6, C7, C8, C9, C10, C11, C12, C13, C14, C15, C16, C17, C18, C19: 0,1uF; C_0805_2012Metric_Pad1.18x1.45mm_HandSolder
C20, C22: 1uF; C_0805_2012Metric_Pad1.18x1.45mm_HandSolder
C21: 22uF; C_0805_2012Metric_Pad1.18x1.45mm_HandSolder
D1: LED_GREEN; LED_0805_2012Metric_Pad1.15x1.40mm_HandSolder
J4: Conn_01x07; JST_B7B-ZR_LF__SN_
R1: 10K; R_0805_2012Metric_Pad1.20x1.40mm_HandSolder
R6: 5.1k; R_0805_2012Metric_Pad1.20x1.40mm_HandSolder; LCSC p/n C84375
U1: HALL_SENSOR_1; TO-92_Inline
U2: HALL_SENSOR_2; TO-92_Inline
U3: HALL_SENSOR3; TO-92_Inline
U4: HALL_SENSOR4; TO-92_Inline
U5: CD74HC4067M; SOIC-24W_7.5x15.4mm_P1.27mm
U6: HALL_SENSOR_5; TO-92_Inline
U7: HALL_SENSOR_6; TO-92_Inline
U8: HALL_SENSOR7; TO-92_Inline
U9: HALL_SENSOR8; TO-92_Inline
U10: HALL_SENSOR_9; TO-92_Inline
U11: HALL_SENSOR_13; TO-92_Inline
U12: HALL_SENSOR_10; TO-92_Inline
U13: HALL_SENSOR_14; TO-92_Inline
U14: HALL_SENSOR11; TO-92_Inline
U15: HALL_SENSOR15; TO-92_Inline
U16: HALL_SENSOR12; TO-92_Inline
U17: HALL_SENSOR16; TO-92_Inline

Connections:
+3V3: C3.1, C4.1, C5.1, C6.1, C7.1, C8.1, C9.1, C10.1, C11.1, C12.1, C13.1, C14.1, C15.1, C16.1, C17.1, C18.1, C19.1, C20.1, C21.1, C22.1, J4.7, R6.1, U1.1 (VCC), U2.1 (VCC), U3.1 (VCC), U4.1 (VCC), U5.24 (VCC), U6.1 (VCC), U7.1 (VCC), U8.1 (VCC), U9.1 (VCC), U10.1 (VCC), U11.1 (VCC), U12.1 (VCC), U13.1 (VCC), U14.1 (VCC), U15.1 (VCC), U16.1 (VCC), U17.1 (VCC)
GND: C3.2, C4.2, C5.2, C6.2, C7.2, C8.2, C9.2, C10.2, C11.2, C12.2, C13.2, C14.2, C15.2, C16.2, C17.2, C18.2, C19.2, C20.2, C21.2, C22.2, D1.1 (K), J4.1, R1.2, U1.2 (GND), U2.2 (GND), U3.2 (GND), U4.2 (GND), U5.12 (GND), U6.2 (GND), U7.2 (GND), U8.2 (GND), U9.2 (GND), U10.2 (GND), U11.2 (GND), U12.2 (GND), U13.2 (GND), U14.2 (GND), U15.2 (GND), U16.2 (GND), U17.2 (GND)
MUX1: J4.5, U5.10 (S0)
MUX2: J4.4, U5.11 (S1)
MUX3: J4.3, U5.14 (S2)
MUX4: J4.2, U5.13 (S3)
unnamed: D1.2 (A), R6.2
unnamed: R1.1, U5.15 (~E)
Output: J4.6, U5.1 (COM)
hall1: U1.3 (OUT), U5.9 (I0)
hall2: U2.3 (OUT), U5.8 (I1)
hall3: U3.3 (OUT), U5.7 (I2)
hall4: U4.3 (OUT), U5.6 (I3)
hall5: U5.5 (I4), U6.3 (OUT)
hall6: U5.4 (I5), U7.3 (OUT)
hall7: U5.3 (I6), U8.3 (OUT)
hall8: U5.2 (I7), U9.3 (OUT)
hall9: U5.23 (I8), U10.3 (OUT)
hall10: U5.22 (I9), U12.3 (OUT)
hall11: U5.21 (I10), U14.3 (OUT)
hall12: U5.20 (I11), U16.3 (OUT)
hall13: U5.19 (I12), U11.3 (OUT)
hall14: U5.18 (I13), U13.3 (OUT)
hall15: U5.17 (I14), U15.3 (OUT)
hall16: U5.16 (I15), U17.3 (OUT)

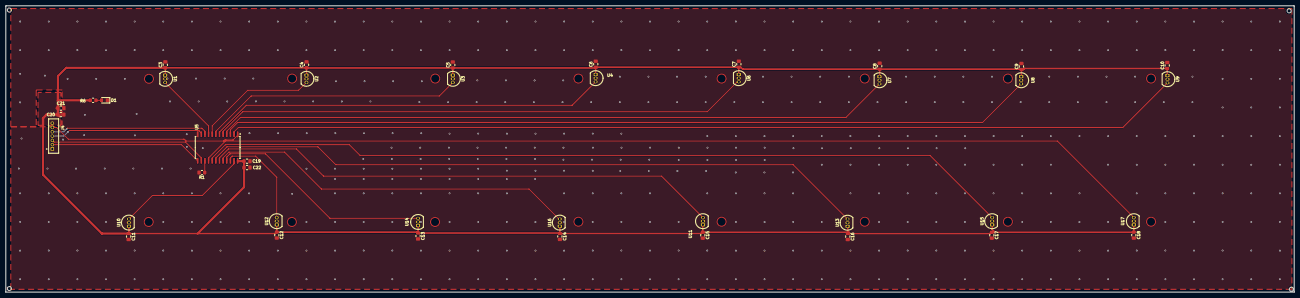
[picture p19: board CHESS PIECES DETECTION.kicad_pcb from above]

Board: 2 copper layers, 450.0 x 100.0 mm, 41 parts (0 on the bottom side), 25 nets.

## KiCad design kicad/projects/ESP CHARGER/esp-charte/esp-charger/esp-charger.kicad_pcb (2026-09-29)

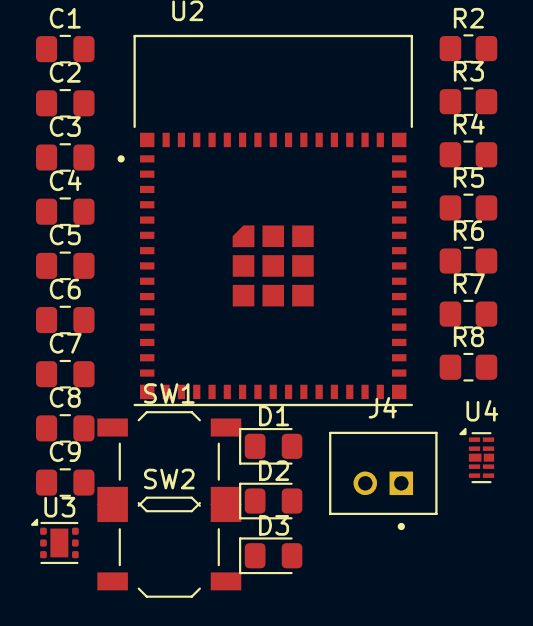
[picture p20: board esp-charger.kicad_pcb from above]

Board: 2 copper layers, 25 parts (0 on the bottom side), 13 nets, no tracks yet.

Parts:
C1, C2, C3, C4: 1uF; C_0805_2012Metric_Pad1.18x1.45mm_HandSolder
C5: C; C_0805_2012Metric_Pad1.18x1.45mm_HandSolder
C6, C8, C9: 0.1uF; C_0805_2012Metric_Pad1.18x1.45mm_HandSolder
C7: 10uF; C_0805_2012Metric_Pad1.18x1.45mm_HandSolder
D1, D2, D3: LED; LED_0805_2012Metric_Pad1.15x1.40mm_HandSolder
J4: B2B-PH-K-S_LF__SN_; JST_B2B-PH-K-S_LF__SN_
R2: 1M; R_0805_2012Metric_Pad1.20x1.40mm_HandSolder
R3: 200k; R_0805_2012Metric_Pad1.20x1.40mm_HandSolder
R4: 540; R_0805_2012Metric_Pad1.20x1.40mm_HandSolder
R5, R6, R7, R8: 1k; R_0805_2012Metric_Pad1.20x1.40mm_HandSolder
SW1: RESET; SW_SPST_TL3342
SW2: BOOT; SW_SPST_TL3342
U2: ESP32-S3-MINI-1-N8; XCVR_ESP32-S3-MINI-1-N8
U3: TLV75801PDRV; WSON-6-1EP_2x2mm_P0.65mm_EP1x1.6mm
U4: D3V3XA4B10LP; Diodes_UDFN-10_1.0x2.5mm_P0.5mm

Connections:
3V3: C4.1, C6.1, C7.1, R2.1, R7.1, R8.1, U2.3 (3V3), U3.1 (OUT)
5V_IN: C1.1, C5.1, U4.4, U4.7 (NC)
GND: C1.2, C2.2, C3.2, C4.2, C5.2, C6.2, C7.2, C8.2, C9.2, D3.1 (K), J4.2, R3.2, R4.2, SW1.1, SW1.2, SW2.1, SW2.2, U2.1 (GND), U2.2 (GND), U2.42 (GND), U2.43 (GND), U2.46 (GND), U2.47 (GND), U2.48 (GND), U2.49 (GND), U2.50 (GND), U2.51 (GND), U2.52 (GND), U2.53 (GND), U2.54 (GND), U2.55 (GND), U2.56 (GND), U2.57 (GND), U2.58 (GND), U2.59 (GND), U2.60 (GND), U2.61 (GND), U2.61_1 (GND), U2.61_2 (GND), U2.61_3 (GND), U2.61_4 (GND), U2.61_5 (GND), U2.61_6 (GND), U2.61_7 (GND), U2.61_8 (GND), U2.62 (GND), U2.63 (GND), U2.64 (GND), U2.65 (GND), U3.3 (GND), U3.7 (GND)
unnamed: D1.2 (A), R5.2
unnamed: D2.2 (A), R6.2
unnamed: D3.2 (A), R7.2
unnamed: C8.1, R8.2, U2.45 (EN)
unnamed: C9.1, U2.4 (IO0)
unnamed: C2.1, C3.1, J4.1, R5.1, R6.1, U3.4 (EN), U3.6 (IN)
unnamed: R2.2, R3.1, U3.2 (FB)
unnamed: U4.3 (VSS), U4.8 (VSS)
USB_N: U2.23 (IO19), U4.1, U4.10 (NC)
USB_P: U2.24 (IO20), U4.2, U4.9 (NC)

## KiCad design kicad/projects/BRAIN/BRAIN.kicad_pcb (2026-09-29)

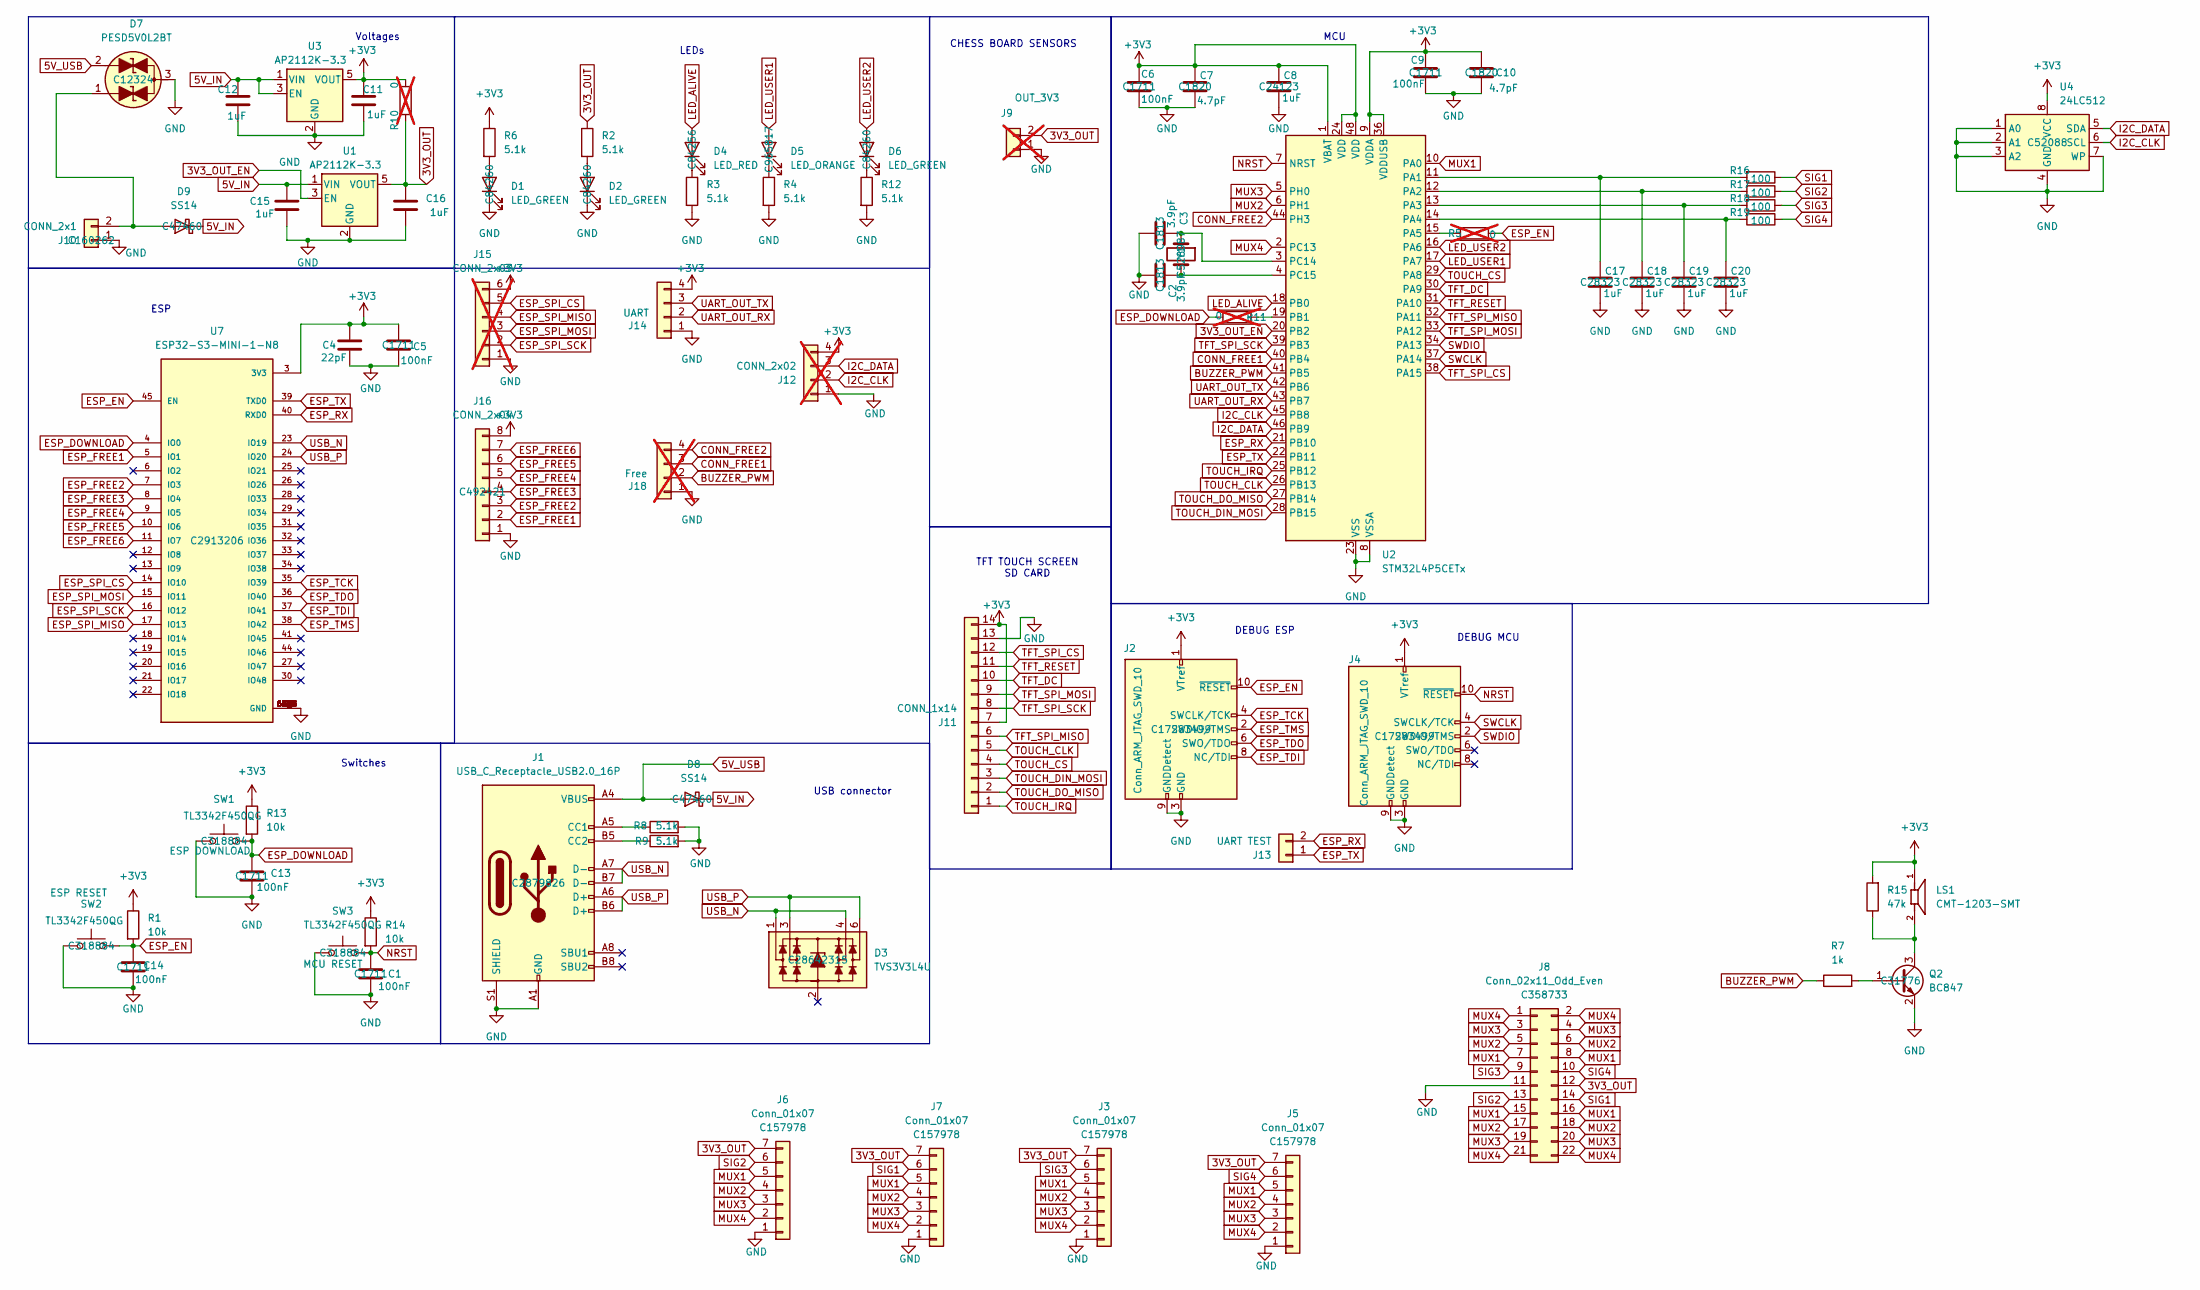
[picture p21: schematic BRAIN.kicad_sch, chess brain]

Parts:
C1, C5, C6, C9, C13, C14: 100nF; C_0805_2012Metric_Pad1.18x1.45mm_HandSolder; LCSC p/n C1711
C2, C3: 3.9pF; C_0805_2012Metric_Pad1.18x1.45mm_HandSolder; LCSC p/n C1813
C4: 22pF; C_0805_2012Metric_Pad1.18x1.45mm_HandSolder; LCSC p/n C1804
C7, C10: 4.7pF; C_0805_2012Metric_Pad1.18x1.45mm_HandSolder; LCSC p/n C1820
C8, C11, C12, C15, C16: 1uF; C_0805_2012Metric_Pad1.18x1.45mm_HandSolder; LCSC p/n C24123
C17, C18, C19, C20: 1uF; C_0805_2012Metric_Pad1.18x1.45mm_HandSolder; LCSC p/n C28323
D1, D2, D6: LED_GREEN; LED_0805_2012Metric_Pad1.15x1.40mm_HandSolder; LCSC p/n C84260
D3: TVS3V3L4U; TSOP-6_1.65x3.05mm_P0.95mm; LCSC p/n C28642315
D4: LED_RED; LED_0805_2012Metric_Pad1.15x1.40mm_HandSolder; LCSC p/n C84256
D5: LED_ORANGE; LED_0805_2012Metric_Pad1.15x1.40mm_HandSolder; LCSC p/n C965817
D7: PESD5V0L2BT; SOT-23; LCSC p/n C12324
D8, D9: SS14; D_SMA; LCSC p/n C47460
J1: USB_C_Receptacle_USB2.0_16P; USB_C_Receptacle_GCT_USB4105-xx-A_16P_TopMnt_Horizontal_Mod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; LCSC p/n C2879826
J2, J4: Conn_ARM_JTAG_SWD_10; GCT_BD125-10-A-0305-0580-L-B; LCSC p/n C17283499
J3, J5, J6, J7: Conn_01x07; JST_B7B-ZR_LF__SN_; LCSC p/n C157978
J8: Conn_02x11_Odd_Even; PinSocket_2x11_P2.54mm_Vertical; LCSC p/n C358733
J9: CONN_01x02; PinSocket_1x02_P2.54mm_Vertical; LCSC p/n C2935896; not fitted
J10: CONN_2x1; JST_EH_B2B-EH-A_1x02_P2.50mm_Vertical; LCSC p/n C160262
J11: CONN_1x14; PinSocket_1x14_P2.54mm_Vertical; LCSC p/n C2883731
J12: CONN_2x02; PinHeader_2x02_P2.54mm_Vertical; LCSC p/n C160338; not fitted
J13: UART TEST; PinHeader_1x02_P2.54mm_Vertical; LCSC p/n C234182
J14: UART; PinHeader_1x04_P2.54mm_Vertical; LCSC p/n C2691448
J15: CONN_2x03; PinHeader_2x03_P2.54mm_Vertical; LCSC p/n C492421; not fitted
J16: CONN_2x04; PinHeader_2x04_P2.54mm_Vertical; LCSC p/n C492421
J18: Free; PinHeader_1x04_P2.54mm_Vertical; LCSC p/n C2691448; not fitted
LS1: CMT-1203-SMT; CUI_CMT-1203-SMT; PARTREV 1.01
Q2: BC847; SOT-23; LCSC p/n C31776
R1, R13, R14: 10k; R_0805_2012Metric_Pad1.20x1.40mm_HandSolder; LCSC p/n C84376
R2, R3, R4, R6, R8, R9, R12: 5.1k; R_0805_2012Metric_Pad1.20x1.40mm_HandSolder; LCSC p/n C84375
R5, R10, R11: 0; R_0805_2012Metric_Pad1.20x1.40mm_HandSolder; not fitted
R7: 1k; R_0805_2012Metric_Pad1.20x1.40mm_HandSolder; LCSC p/n C95781
R15: 47k; R_0805_2012Metric_Pad1.20x1.40mm_HandSolder; LCSC p/n C126351
R16, R17, R18, R19: 100; R_0805_2012Metric_Pad1.20x1.40mm_HandSolder; LCSC p/n C17408
SW1, SW2, SW3: TL3342F450QG; SW_SPST_TL3342; LCSC p/n C318884
U1, U3: AP2112K-3.3; SOT-23-5; LCSC p/n C23380830
U2: STM32L4P5CETx; LQFP-48_7x7mm_P0.5mm; LCSC p/n C3227057
U4: 24LC512; SOIC-8_3.9x4.9mm_P1.27mm; LCSC p/n C52088
U7: ESP32-S3-MINI-1-N8; XCVR_ESP32-S3-MINI-1-N8; PARTREV v0.6; LCSC p/n C2913206
Y1: NX3215SA-32.768KHZ-EXS00A-MU00525; Crystal_SMD_MicroCrystal_CC7V-T1A-2Pin_3.2x1.5mm_HandSolder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; LCSC p/n C528987

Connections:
3V3_OUT: C16.1, J3.7, J5.7, J6.7, J7.7, J8.12, J9.2, R2.1, R10.1, U1.5 (VOUT)
3V3_OUT_EN: U1.3 (EN), U2.20 (PB2)
5V_IN: C12.1, C15.1, D8.1 (K), D9.1 (K), U1.1 (VIN), U3.1 (VIN), U3.3 (EN)
5V_USB: D7.2 (A2), D8.2 (A), J1.A4 (VBUS), J1.A9 (VBUS), J1.B4 (VBUS), J1.B9 (VBUS)
+3V3: C4.1, C5.1, C6.1, C7.1, C8.1, C9.1, C10.1, C11.1, J2.1 (VTref), J4.1 (VTref), J11.7, J11.14, J12.4, J14.4, J15.6, J16.8, LS1.1, R1.1, R6.1, R10.2, R13.1, R14.1, R15.2, U2.1 (VBAT), U2.9 (VDDA), U2.24 (VDD), U2.36 (VDDUSB), U2.48 (VDD), U3.5 (VOUT), U4.8 (VCC), U7.3 (3V3)
BUZZER_PWM: J18.2, R7.1, U2.41 (PB5)
CONN_FREE1: J18.3, U2.40 (PB4)
CONN_FREE2: J18.4, U2.44 (PH3)
ESP_DOWNLOAD: C13.1, R11.2, R13.2, SW1.2, U7.4 (IO0)
ESP_EN: C14.1, J2.10 (~RESET), R1.2, R5.2, SW2.2, U7.45 (EN)
ESP_FREE1: J16.2, U7.5 (IO1)
ESP_FREE2: J16.3, U7.7 (IO3)
ESP_FREE3: J16.4, U7.8 (IO4)
ESP_FREE4: J16.5, U7.9 (IO5)
ESP_FREE5: J16.6, U7.10 (IO6)
ESP_FREE6: J16.7, U7.11 (IO7)
ESP_RX: J13.2, U2.21 (PB10), U7.40 (RXD0)
ESP_SPI_CS: J15.5, U7.14 (IO10)
ESP_SPI_MISO: J15.4, U7.17 (IO13)
ESP_SPI_MOSI: J15.3, U7.15 (IO11)
ESP_SPI_SCK: J15.2, U7.16 (IO12)
ESP_TCK: J2.4 (SWCLK/TCK), U7.35 (IO39)
ESP_TDI: J2.8 (NC/TDI), U7.37 (IO41)
ESP_TDO: J2.6 (SWO/TDO), U7.36 (IO40)
ESP_TMS: J2.2 (SWDIO/TMS), U7.38 (IO42)
ESP_TX: J13.1, U2.22 (PB11), U7.39 (TXD0)
GND: C1.1, C2.2, C3.2, C4.2, C5.2, C6.2, C7.2, C8.2, C9.2, C10.2, C11.2, C12.2, C13.2, C14.2, C15.2, C16.2, C17.2, C18.2, C19.2, C20.2, D1.1 (K), D2.1 (K), D7.3 (Com), J1.A1 (GND), J1.A12 (GND), J1.B1 (GND), J1.B12 (GND), J1.S1 (SHIELD), J2.3 (GND), J2.5 (GND), J2.9 (GNDDetect), J3.1, J4.3 (GND), J4.5 (GND), J4.9 (GNDDetect), J5.1, J6.1, J7.1, J8.11, J9.1, J10.1, J11.13, J12.1, J14.1, J15.1, J16.1, J18.1, Q2.2 (E), R3.2, R4.2, R8.2, R9.2, R12.2, SW1.1, SW2.1, SW3.1, U1.2 (GND), U2.8 (VSSA), U2.23 (VSS), U2.35 (VSS), U2.47 (VSS), U3.2 (GND), U4.1 (A0), U4.2 (A1), U4.3 (A2), U4.4 (GND), U4.7 (WP), U7.1 (GND), U7.2 (GND), U7.42 (GND), U7.43 (GND), U7.46 (GND), U7.47 (GND), U7.48 (GND), U7.49 (GND), U7.50 (GND), U7.51 (GND), U7.52 (GND), U7.53 (GND), U7.54 (GND), U7.55 (GND), U7.56 (GND), U7.57 (GND), U7.58 (GND), U7.59 (GND), U7.60 (GND), U7.61 (GND), U7.61_1 (GND), U7.61_2 (GND), U7.61_3 (GND), U7.61_4 (GND), U7.61_5 (GND), U7.61_6 (GND), U7.61_7 (GND), U7.61_8 (GND), U7.62 (GND), U7.63 (GND), U7.64 (GND), U7.65 (GND)
I2C_CLK: J12.2, U2.45 (PB8), U4.6 (SCL)
I2C_DATA: J12.3, U2.46 (PB9), U4.5 (SDA)
LED_ALIVE: D4.2 (A), U2.18 (PB0)
LED_USER1: D5.2 (A), U2.17 (PA7)
LED_USER2: D6.2 (A), U2.16 (PA6)
MUX1: J3.5, J5.5, J6.5, J7.5, J8.7, J8.8, J8.15, J8.16, U2.10 (PA0)
MUX2: J3.4, J5.4, J6.4, J7.4, J8.5, J8.6, J8.17, J8.18, U2.6 (PH1)
MUX3: J3.3, J5.3, J6.3, J7.3, J8.3, J8.4, J8.19, J8.20, U2.5 (PH0)
MUX4: J3.2, J5.2, J6.2, J7.2, J8.1, J8.2, J8.21, J8.22, U2.2 (PC13)
NRST: C1.2, J4.10 (~RESET), R14.2, SW3.2, U2.7 (NRST)
unnamed: D1.2 (A), R6.2
unnamed: D2.2 (A), R2.2
unnamed: D4.1 (K), R3.1
unnamed: D5.1 (K), R4.1
unnamed: D6.1 (K), R12.1
unnamed: D7.1 (A1), D9.2 (A), J10.2
unnamed: J1.A5 (CC1), R8.1
unnamed: J1.B5 (CC2), R9.1
unnamed: Q2.1 (B), R7.2
unnamed: LS1.2, Q2.3 (C), R15.1
unnamed: C17.1, R16.2, U2.11 (PA1)
unnamed: C18.1, R17.2, U2.12 (PA2)
unnamed: C19.1, R18.2, U2.13 (PA3)
unnamed: C20.1, R19.2, U2.14 (PA4)
unnamed: R5.1, U2.15 (PA5)
unnamed: R11.1, U2.19 (PB1)
unnamed: C3.1, U2.3 (PC14), Y1.1
unnamed: C2.1, U2.4 (PC15), Y1.2
SIG1: J7.6, J8.14, R16.1
SIG2: J6.6, J8.13, R17.1
SIG3: J3.6, J8.9, R18.1
SIG4: J5.6, J8.10, R19.1
SWCLK: J4.4 (SWCLK/TCK), U2.37 (PA14)
SWDIO: J4.2 (SWDIO/TMS), U2.34 (PA13)
TFT_DC: J11.10, U2.30 (PA9)
TFT_RESET: J11.11, U2.31 (PA10)
TFT_SPI_CS: J11.12, U2.38 (PA15)
TFT_SPI_MISO: J11.6, U2.32 (PA11)
TFT_SPI_MOSI: J11.9, U2.33 (PA12)
TFT_SPI_SCK: J11.8, U2.39 (PB3)
TOUCH_CLK: J11.5, U2.26 (PB13)
TOUCH_CS: J11.4, U2.29 (PA8)
TOUCH_DIN_MOSI: J11.3, U2.28 (PB15)
TOUCH_DO_MISO: J11.2, U2.27 (PB14)
TOUCH_IRQ: J11.1, U2.25 (PB12)
UART_OUT_RX: J14.2, U2.43 (PB7)
UART_OUT_TX: J14.3, U2.42 (PB6)
USB_N: D3.1 (L1), D3.4 (L3), J1.A7 (D-), J1.B7 (D-), U7.23 (IO19)
USB_P: D3.3 (L2), D3.6 (L4), J1.A6 (D+), J1.B6 (D+), U7.24 (IO20)

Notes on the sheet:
MCU
LEDs
DEBUG MCU
CHESS BOARD SENSORS
TFT TOUCH SCREEN SD CARD
ESP
Switches
USB connector
Voltages
DEBUG ESP

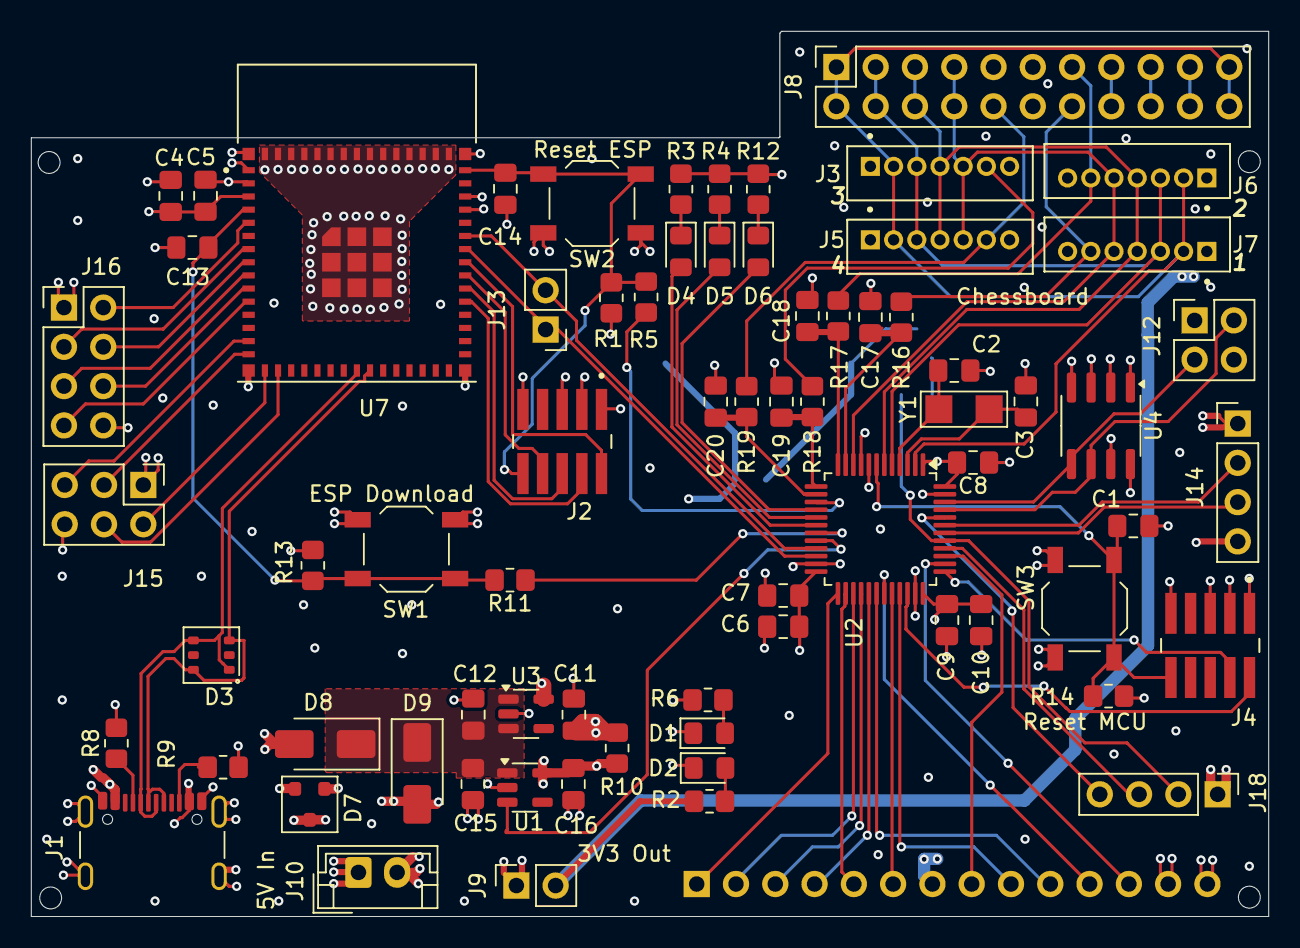
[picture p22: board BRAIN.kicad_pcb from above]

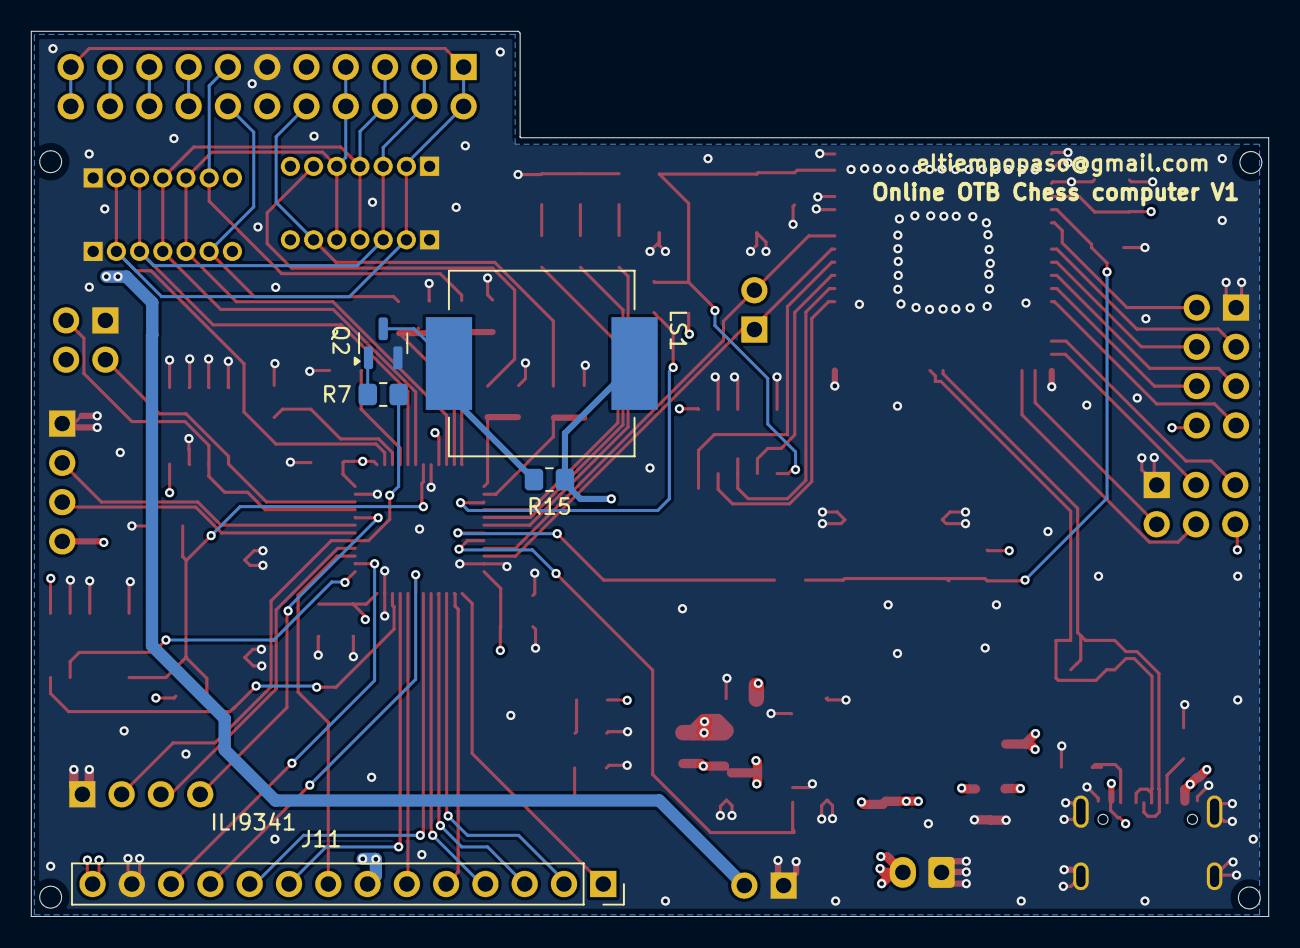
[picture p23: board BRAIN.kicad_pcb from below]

Board: 4 copper layers, 80.0 x 57.2 mm, 76 parts (5 on the bottom side), 76 nets.

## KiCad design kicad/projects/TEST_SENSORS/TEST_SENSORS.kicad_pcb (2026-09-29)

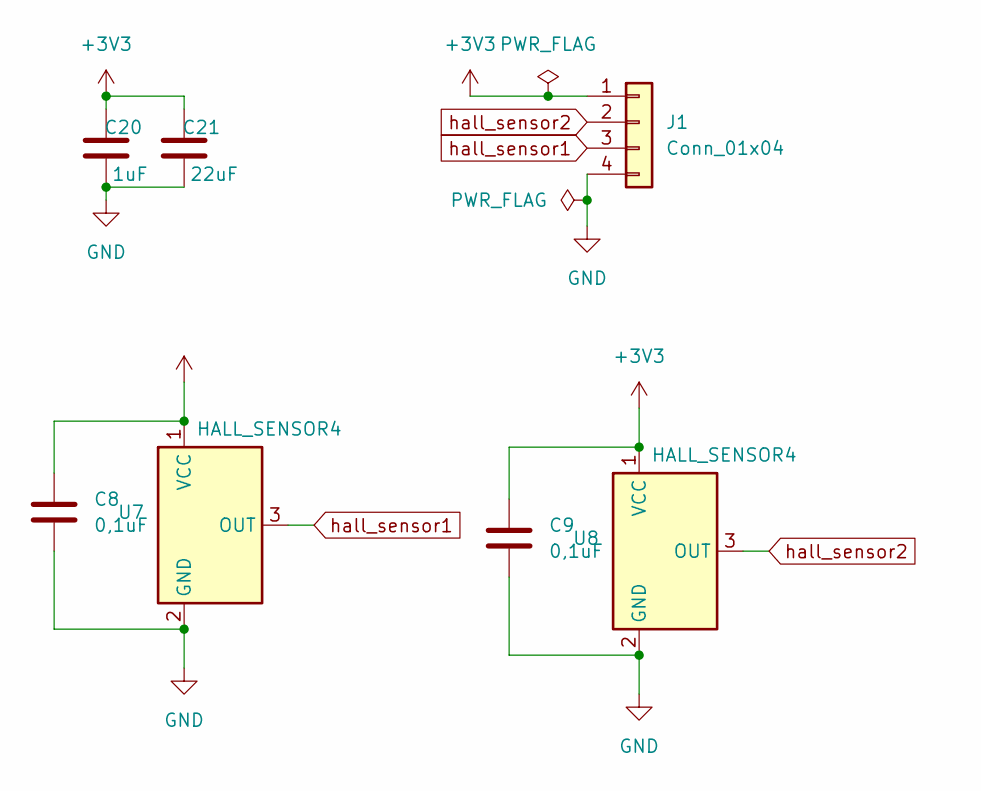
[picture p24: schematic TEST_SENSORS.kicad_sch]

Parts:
C8, C9: 0,1uF; C_0805_2012Metric_Pad1.18x1.45mm_HandSolder
C20: 1uF; C_0805_2012Metric_Pad1.18x1.45mm_HandSolder
C21: 22uF; C_0805_2012Metric_Pad1.18x1.45mm_HandSolder
J1: Conn_01x04; PinHeader_1x04_P2.54mm_Vertical
U7, U8: HALL_SENSOR4; TO-92_Inline

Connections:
+3V3: C8.1, C9.1, C20.1, C21.1, J1.1, U7.1 (VCC), U8.1 (VCC)
GND: C8.2, C9.2, C20.2, C21.2, J1.4, U7.2 (GND), U8.2 (GND)
hall_sensor1: J1.3, U7.3 (OUT)
hall_sensor2: J1.2, U8.3 (OUT)

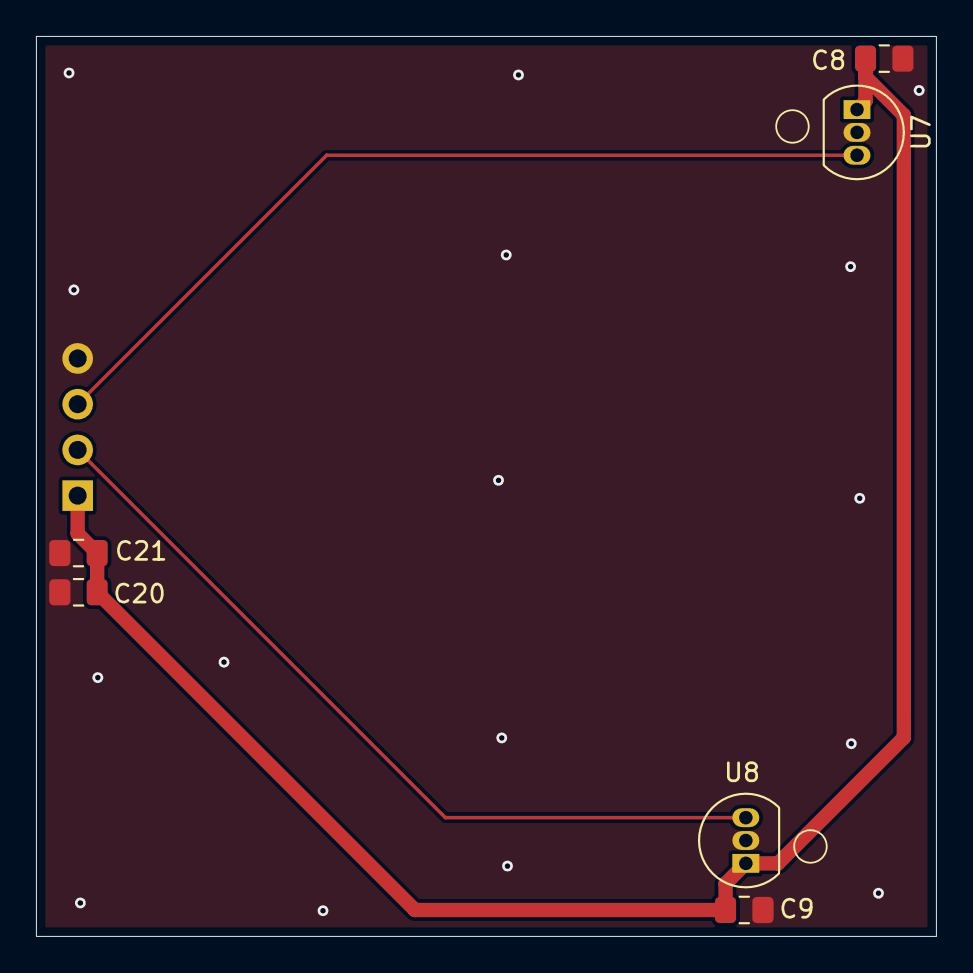
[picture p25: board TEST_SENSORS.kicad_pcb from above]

Board: 2 copper layers, 50.0 x 50.0 mm, 7 parts (1 on the bottom side), 4 nets.

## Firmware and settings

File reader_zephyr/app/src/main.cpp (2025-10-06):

/*
 * Copyright (c) 2017 Linaro Limited
 *
 * SPDX-License-Identifier: Apache-2.0
 */


#include <zephyr/kernel.h>
#include <zephyr/device.h>
#include <zephyr/devicetree.h>
#include <zephyr/drivers/gpio.h>
#include <zephyr/drivers/adc.h>
#include <zephyr/sys/printk.h>
#include <zephyr/sys/util.h>
#include <zephyr/sys/__assert.h>
#include <zephyr/shell/shell.h>

#include <string.h>
#include <ctype.h>

#include "Led.hpp"
#include "SensorsMatrix.h"
#include "UartSender.h"
#include "FlashStorage.h"

/* size of stack area used by each thread */
#define STACKSIZE 1024

/* scheduling priority used by each thread */
#define PRIORITY_NORMAL 7
#define PRIORITY_HIGH 5

#define LED0_NODE DT_ALIAS(led0)

#if !DT_NODE_HAS_STATUS(LED0_NODE, okay)
#error "Unsupported board: led0 devicetree alias is not defined"
#endif

#define LED1_NODE DT_ALIAS(led1)

#if !DT_NODE_HAS_STATUS(LED1_NODE, okay)
#error "Unsupported board: led1 devicetree alias is not defined"
#endif


bool initialized = false;

K_SEM_DEFINE(my_sem, 0, 1);  // Initial count = 0, Max count = 1


SensorsMatrix sm;
FlashStorage fs;
UartSender uart;

void alive(void) {
	Led aLed( GPIO_DT_SPEC_GET_OR(LED0_NODE, gpios, {0}) );

	if ( aLed.initialize() != 0 ) {
		return;
	}

	while (1) {
		aLed.toogle();

		k_msleep(1000);
	}
}

void matrix(void) {
	while (!initialized)
		k_msleep(1);

	printk("matrix periodic refresh starts.\n");

	int iteration = 0;
	while (1) {

		if (sm.refresh()) {
			k_sem_give(&my_sem);
		} else {
			//printk("No changes\n");
		}

		k_msleep(200); // refresh takes 65ms aprox. Thus 64+200 is about 4 samples/second
		iteration++;
	}
}

bool board_inverted = false;
void changes_notifier(void) {
	Led aLed( GPIO_DT_SPEC_GET_OR(LED1_NODE, gpios, {0}) );

	if ( aLed.initialize() != 0 ) {
		printk("cannot initialize LED1");
		return;
	}

	uint8_t aMatrix[8][8];
	uint8_t packed_board[8];    // Each byte = 1 row
	char uart_msg[64];          // UART message buffer



	while (!initialized) k_msleep(1);
        printk("board monitor starts.\n");

	while (1) {

		k_sem_take(&my_sem, K_FOREVER);

		sm.getPosition(aMatrix);

		for (int row = 0; row < 8; ++row) {
			uint8_t bits = 0;

			for (int col = 0; col < 8; ++col) {
				if (aMatrix[row][col] != 0) {
					bits |= (1 << (board_inverted? col : (7 - col)));  // col 0 is MSB
				}
			}

			packed_board[row] = bits;
		}

		int len = snprintf(uart_msg, sizeof(uart_msg),
			"BOARD:%02X-%02X-%02X-%02X-%02X-%02X-%02X-%02X\r\n",
			packed_board[7], packed_board[6],
			packed_board[5], packed_board[4],
			packed_board[3], packed_board[2],
			packed_board[1], packed_board[0]);

		printk("Sent: %s", uart_msg);
		uart.send(uart_msg);
		aLed.toogle();
	}

	return;
}

K_THREAD_DEFINE(alive_id, STACKSIZE, alive, NULL, NULL, NULL, PRIORITY_NORMAL, 0, 0);
K_THREAD_DEFINE(matrix_reader_id, 4096, matrix, NULL, NULL, NULL, PRIORITY_NORMAL, 0, 0);
K_THREAD_DEFINE(changes_notifier_id, STACKSIZE, changes_notifier, NULL, NULL, NULL, PRIORITY_HIGH, 0, 0);

int main(void) {

	if (fs.initialize() != 0) {
		printk("Error: Could not initialize flash storage\n");
		return -1;
	}

	if (sm.initialize() != 0) {
		printk("Error: Could not initialize sensors matrix\n");
		return -1;
	}

	if (!uart.initialize()) {
		printk("ERROR INITIALIZING Uart");
		return -1;
	}

	storage_data sd;
	if (fs.read(sd) == 0) {
		printk("Calibrations found in flash. Let's use them\n");

		sm.setCalibrations(sd.calibrations);
	} else {
		printk("No calibrations found in flash. Calibrating sensors.\n");

		if (sm.calibrate() != 0) {
			printk("Error: Could not calibrate sensors matrix\n");
			return -1;
		}
	}

	char * buffer = sm.formatCalibrations();
	if (buffer) {
		printk("%s", buffer);
		k_free(buffer);
	}

	printk("Hw initialized.\n");
	initialized = true;

	return 0;
}

// Uart shell commands
static int cmd_cb_calibrate(const struct shell *shell, size_t argc, char **argv) {
    shell_print(shell, "Calibrating..");

    sm.calibrate();

    return 0;
}

static int cmd_cb_printCalibrations(const struct shell *shell, size_t argc, char **argv) {
	char * buffer = sm.formatCalibrations();
	if (buffer) {
		shell_print(shell, "%s", buffer);

		k_free(buffer);
	} else {
		shell_print(shell, "Error. Could not format calibrations to be printed");
	}

    return 0;
}

static int cmd_cb_saveCalibrations(const struct shell *shell, size_t argc, char **argv) {
	shell_print(shell, "Saving calibrations in flash storage...");
	storage_data sd;
	sm.getCalibrations(sd.calibrations);

	if (fs.write(sd) == 0) {
		shell_print(shell, "SAVED!\n");
	} else {
		shell_print(shell, "ERROR!\n");
	}

    return 0;
}

static int cmd_cb_loadCalibrations(const struct shell *shell, size_t argc, char **argv) {
	shell_print(shell, "Loading calibrations from flash...");
	storage_data sd;
	if (fs.read(sd) == 0) {
		sm.setCalibrations(sd.calibrations);
		shell_print(shell, "LOADED OK!\n");
	} else {
		shell_print(shell, "No calibrations found. Calibrate manually and save them.\n");
	}

    return 0;
}

static int cmd_cb_setBoardInverted(const struct shell *shell, size_t argc, char **argv) {
    if (argc != 2) {
        shell_print(shell, "Usage: cb setBoardInverted <true/false>");
        return -EINVAL;
    }

    const char *param = argv[1];

    if (strcmp(param, "true") != 0) {
	    board_inverted = false;

    } else {
	    board_inverted = true;
    }

    shell_print(shell, "Inversion set to: %s", board_inverted? "true":"false");

    return 0;
}


static int cmd_cb_readmv(const struct shell *shell, size_t argc, char **argv) {
    if (argc != 2) {
        shell_print(shell, "Usage: cb readMv <square>");
        return -EINVAL;
    }

    const char *square = argv[1];

    if (strlen(square) != 2) {
        shell_print(shell, "Invalid format. Square must be 2 characters (e.g., A1).");
        return -EINVAL;
    }

    char file = toupper(square[0]);
    char rank = square[1];

    if (file < 'A' || file > 'H' || rank < '1' || rank > '8') {
        shell_print(shell, "Invalid square. Must be between A1 and H8.");
        return -EINVAL;
    }

    int file_index = file - 'A';  // A=0, B=1, ..., H=7
    int rank_index = 7-(rank - '1');  // 1=0, ..., 8=7

    const int32_t mv = sm.getVoltage(rank_index, file_index);
    shell_print(shell, "%s (%d %d): %dmv", square, file_index, rank_index, mv);

    return 0;
}

static int cmd_cb_readGauss(const struct shell *shell, size_t argc, char **argv) {
    if (argc != 2) {
        shell_print(shell, "Usage: cb readMv <square>");
        return -EINVAL;
    }

    const char *square = argv[1];

    if (strlen(square) != 2) {
        shell_print(shell, "Invalid format. Square must be 2 characters (e.g., A1).");
        return -EINVAL;
    }

    char file = toupper(square[0]);
    char rank = square[1];

    if (file < 'A' || file > 'H' || rank < '1' || rank > '8') {
        shell_print(shell, "Invalid square. Must be between A1 and H8.");
        return -EINVAL;
    }

    int file_index = file - 'A';  // A=0, B=1, ..., H=7
    int rank_index = 7-(rank - '1');  // 1=0, ..., 8=7

    const int32_t gauss = (int32_t)sm.getGauss(rank_index, file_index);
    shell_print(shell, "%s (%d %d): %dG", square, file_index, rank_index, gauss);

    return 0;
}

static int cmd_cb_printVoltages(const struct shell *shell, size_t argc, char **argv) {
	char * buffer = sm.formatVoltages();
	if (buffer) {
		shell_print(shell, "%s", buffer);

		k_free(buffer);
	} else {
		shell_print(shell, "Error. Could not format voltages to be printed");
	}

    return 0;
}

static int cmd_cb_printGaussesMatrix (const struct shell *shell, size_t argc, char **argv) {
	char * buffer = sm.formatGaussesMatrix();
	if (buffer) {
		shell_print(shell, "%s", buffer);

		k_free(buffer);
	} else {
		shell_print(shell, "Error. Could not format gauss matrix to be printed");
	}

    return 0;
}


SHELL_STATIC_SUBCMD_SET_CREATE(sub_cb,
    SHELL_CMD(calibrate, NULL, "Sensors calibration", cmd_cb_calibrate),
    SHELL_CMD(printCalibrations, NULL, "print calibrations", cmd_cb_printCalibrations),
    SHELL_CMD(saveCalbrations  , NULL, "save current calibrations to flash", cmd_cb_saveCalibrations),
    SHELL_CMD(loadCalbrations  , NULL, "save current calibrations to flash", cmd_cb_loadCalibrations),

    SHELL_CMD(setBoardInverted  , NULL, "Inverts the board", cmd_cb_setBoardInverted),

    SHELL_CMD(readMv,    NULL, "mv of a square", cmd_cb_readmv),
    SHELL_CMD(readGauss, NULL, "gauss of a square", cmd_cb_readGauss),
    SHELL_CMD(printVoltages, NULL, "Print voltages matrix", cmd_cb_printVoltages),
    SHELL_CMD(printGaussesMatrix, NULL, "Print voltages matrix", cmd_cb_printGaussesMatrix),
    SHELL_SUBCMD_SET_END /* Obligatorio para cerrar la lista */
);

SHELL_CMD_REGISTER(cb, &sub_cb, "Chessboard debug commands", NULL);

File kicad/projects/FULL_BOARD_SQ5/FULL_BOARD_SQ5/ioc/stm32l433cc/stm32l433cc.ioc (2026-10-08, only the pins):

Mcu.UserName=STM32L433CCTx
PA0.GPIO_Label=MUX1
PA0.Signal=GPIO_Output
PA1.GPIO_Label=SIG1
PA1.Signal=GPIO_Analog
PA10.GPIO_Label=NRF_CE
PA10.Signal=GPIO_Output
PA11.GPIO_Label=USB_N
PA11.Signal=USB_DM
PA12.GPIO_Label=USB_P
PA12.Signal=USB_DP
PA2.GPIO_Label=SIG2
PA2.Signal=GPIO_Analog
PA3.GPIO_Label=SIG3
PA3.Signal=GPIO_Analog
PA4.GPIO_Label=SIG4
PA4.Signal=GPIO_Analog
PA5.Signal=SPI1_SCK
PA6.Signal=SPI1_MISO
PA7.Signal=SPI1_MOSI
PA8.GPIO_Label=HWREV0
PA8.Signal=GPIO_Input
PA9.GPIO_Label=HWREV1
PA9.Signal=GPIO_Input
PB0.GPIO_Label=NRF_CSN
PB0.Signal=GPIO_Output
PB1.GPIO_Label=FBK_3V3_SENSORS
PB1.Signal=ADCx_IN16
PB12.GPIO_Label=OUT_3V3
PB12.Signal=GPIO_Output
PB2.GPIO_Label=NRF_IRQ
PB2.Signal=GPIO_Output
PB5.GPIO_Label=BUZZER_PWM
PB5.Signal=GPIO_Output
PB6.Signal=USART1_TX
PB7.Signal=USART1_RX
PB8.Signal=I2C1_SCL
PB9.Signal=I2C1_SDA
PC13.GPIO_Label=MUX4
PC13.Signal=GPIO_Output
PH3-BOOT0.GPIO_Label=HWREV2
PH3-BOOT0.Signal=GPIO_Input

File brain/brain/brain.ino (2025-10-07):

#include <Arduino.h>
#include <NimBLEDevice.h>
#include <queue>

std::queue<uint8_t> txQueue;

#define UART_TX_PIN 43
#define UART_RX_PIN 44
#define BAUD_RATE   115200
#define BUFFER_SIZE 1024

// Nordic UART Service UUIDs
#define SERVICE_UUID        "6E400001-B5A3-F393-E0A9-E50E24DCCA9E"
#define CHARACTERISTIC_RX   "6E400002-B5A3-F393-E0A9-E50E24DCCA9E"
#define CHARACTERISTIC_TX   "6E400003-B5A3-F393-E0A9-E50E24DCCA9E"

NimBLEServer* pServer = nullptr;
NimBLECharacteristic* pTxCharacteristic = nullptr;
bool deviceConnected = false;
bool notificationReady = true;

// ---- Callbacks ----
class ServerCallbacks : public NimBLEServerCallbacks {
  void onConnect(NimBLEServer* pServer, NimBLEConnInfo& connInfo) {
    deviceConnected = true;
    Serial.println("BLE Device connected");
  }
  void onDisconnect(NimBLEServer* pServer, NimBLEConnInfo& connInfo, int reason) {
    deviceConnected = false;
    NimBLEDevice::startAdvertising();
    Serial.println("BLE Device disconnected");
  }
};

class RXCallbacks : public NimBLECharacteristicCallbacks {
  void onWrite(NimBLECharacteristic* pCharacteristic, NimBLEConnInfo& connInfo) {
    std::string value = pCharacteristic->getValue();
    for (char c : value) {
      Serial.write(c);
      Serial1.write(c);
    }
  }
};

class TXCallbacks : public NimBLECharacteristicCallbacks {
    void onStatus(NimBLECharacteristic* pCharacteristic, int code) override {
        if (code == 0 || code == BLE_HS_EDONE) {
            notificationReady = true;
        } else {
            Serial.print("Failed with code: ");
            Serial.println(code);
        }
    }
};

// ---- Setup ----
void setup() {
  Serial.begin(BAUD_RATE);
  while (!Serial);
  Serial.println("\n[ESP32-S3] BLE ↔ UART ↔ USB Bridge starting...");

  Serial1.begin(BAUD_RATE, SERIAL_8N1, UART_RX_PIN, UART_TX_PIN);

  // Initialize BLE
  NimBLEDevice::init("ESP32S3_BLE_Bridge");

  Serial.println(NimBLEDevice::getAddress().toString().c_str());

  pServer = NimBLEDevice::createServer();
  pServer->setCallbacks(new ServerCallbacks());

  NimBLEService* pService = pServer->createService(SERVICE_UUID);

  pTxCharacteristic = pService->createCharacteristic(
      CHARACTERISTIC_TX,
      NIMBLE_PROPERTY::INDICATE
  );

  NimBLECharacteristic* pRxCharacteristic = pService->createCharacteristic(
      CHARACTERISTIC_RX,
      NIMBLE_PROPERTY::WRITE | NIMBLE_PROPERTY::WRITE_NR
  );
  pRxCharacteristic->setCallbacks(new RXCallbacks());
  pTxCharacteristic->setCallbacks(new TXCallbacks());

  pService->start();

  NimBLEAdvertising* pAdvertising = NimBLEDevice::getAdvertising();
  pAdvertising->addServiceUUID(SERVICE_UUID);
  pAdvertising->setScanResponseData(NimBLEDevice::getAdvertising()->getAdvertisementData());
  pAdvertising->setMinInterval(0x20);
  pAdvertising->setMaxInterval(0x40);
  NimBLEDevice::startAdvertising();

  NimBLEDevice::setSecurityAuth(false, false, true); // bonding, MITM, secure connections
  
  Serial.println("[BLE] Advertising as 'ESP32S3_BLE_Bridge'");
  Serial.println("Bridge active: USB ↔ UART ↔ BLE\n");
}

// ---- Main Loop ----
void loop() {
  // USB → UART + BLE
  while (Serial.available()) {
    uint8_t c = Serial.read();
    Serial1.write(c);
    if (deviceConnected)
      txQueue.push(c);
  }

  // UART → USB + BLE
  while (Serial1.available()) {
    uint8_t c = Serial1.read();
    Serial.write(c);
    if (deviceConnected)
      txQueue.push(c);
  }

      // Send one byte at a time via BLE if ready
    if (deviceConnected && !txQueue.empty() && notificationReady) {
      static uint8_t buffer[BUFFER_SIZE];
      int len = 0;

      const uint16_t characteristic_max_size = pTxCharacteristic->getValue().max_size();
      const int MAXIMUM_SIZE = characteristic_max_size < BUFFER_SIZE? (int)characteristic_max_size:(int)BUFFER_SIZE;

      while (!txQueue.empty() && len < MAXIMUM_SIZE) {
          buffer[len++] = txQueue.front();
          txQueue.pop();
      }


      pTxCharacteristic->setValue(buffer, len);     
      notificationReady = false;  // wait for onStatus
      pTxCharacteristic->indicate();
    }


}

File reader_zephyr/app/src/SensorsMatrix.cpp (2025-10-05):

#include "SensorsMatrix.h"
#include "utils.h"

#include <zephyr/logging/log.h>

#include "LockObjects.h"

LOG_MODULE_REGISTER(sensormatrix, LOG_LEVEL_DBG);  // or LOG_LEVEL_DBG

#ifndef CONFIG_DETECTION_HISTERESYS_EMPTY
#define CONFIG_DETECTION_HISTERESYS_EMPTY 15
#endif

#ifndef CONFIG_DETECTION_HISTERESYS_PIECE
#define CONFIG_DETECTION_HISTERESYS_PIECE 60
#endif

static const int32_t histeresys_empty_mv = gauss2mv(CONFIG_DETECTION_HISTERESYS_EMPTY);
static const int32_t histeresys_piece_mv = gauss2mv(CONFIG_DETECTION_HISTERESYS_PIECE);

#define NROWS 8
#define NFILES 8

#define BUFFER_SIZE 1 // buffer used to filter position changes.

#if !DT_NODE_EXISTS(DT_PATH(zephyr_user)) || \
	!DT_NODE_HAS_PROP(DT_PATH(zephyr_user), io_channels) || \
	!DT_NODE_HAS_PROP(DT_PATH(zephyr_user), mux_gpios) || \
	!DT_NODE_HAS_PROP(DT_PATH(zephyr_user), enable_gpios)
#error "Unsupported board: zephyr_user devicetree alias is not defined"
#endif

#define DT_SPEC_AND_COMMA(node_id, prop, idx) \
	ADC_DT_SPEC_GET_BY_IDX(node_id, idx),

/* Data of ADC io-channels specified in devicetree. */
static const struct adc_dt_spec adc_channels[] = {
	DT_FOREACH_PROP_ELEM(DT_PATH(zephyr_user), io_channels,
			     DT_SPEC_AND_COMMA)
};

#define DT_GPIO_SPEC_AND_COMMA(node_id, prop, idx) \
	GPIO_DT_SPEC_GET_BY_IDX(node_id, prop, idx),


static const struct gpio_dt_spec gpios_mux[] = {
	DT_FOREACH_PROP_ELEM(DT_PATH(zephyr_user), mux_gpios,
			     DT_GPIO_SPEC_AND_COMMA)
};

static const struct gpio_dt_spec enable_gpios[] = {
	DT_FOREACH_PROP_ELEM(DT_PATH(zephyr_user), enable_gpios,
			     DT_GPIO_SPEC_AND_COMMA)
};

int32_t calibrations[NROWS][NFILES] = {0}; // mv. used to find the 0

int32_t voltages[BUFFER_SIZE][NROWS][NFILES] = {0};
uint8_t current = 0;
uint8_t previous = 0;

uint8_t currentPosition[NROWS][NFILES] = {0}; // 0-empty and 1-piece

K_MUTEX_DEFINE(my_mutex);
K_MUTEX_DEFINE(calib_mutex);

int SensorsMatrix::initialize()
{
	LOG_DBG ("SensorsMatrix::initialize() Initializing Sensors Matrix...");
	int ret;
	int err;
	uint16_t buf;
	struct adc_sequence sequence = {
		.buffer = &buf,
		.buffer_size = sizeof(buf), /* buffer size in bytes, not number of samples */
	};

	if (ARRAY_SIZE(adc_channels) != 4)
	{
		LOG_ERR("Error: Expected 4 elements in adc_channels");
		return -1;
	}

	if (ARRAY_SIZE(gpios_mux) != 4)
	{
		LOG_ERR("Error: Expected 4 elements in gpios_mux");
		return -1;
	}

	if (ARRAY_SIZE(enable_gpios) != 1)
	{
		LOG_ERR("Error: Expected 1 elements in enable_gpios");
		return -1;
	}


	/* Configure channels individually prior to sampling. */
	for (size_t i = 0U; i < 4; i++) {
		if (!adc_is_ready_dt(&adc_channels[i])) {
			LOG_ERR("SensorsMatrix::initialize() ADC controller device %s not ready", adc_channels[i].dev->name);
			return -1;
		}

		err = adc_channel_setup_dt(&adc_channels[i]);
		if (err < 0) {
			LOG_ERR("SensorsMatrix::initialize() Could not setup channel #%d (%d)", i, err);
			return -1;
		}

		LOG_DBG("Configuted ADC CHANNEL %d", adc_channels[i].channel_id);
	}

	/* Configure mux gpios */
	for (size_t nmux = 0U; nmux < 4; nmux++)
	{
		const struct gpio_dt_spec *spec = &gpios_mux[nmux];
		if (!device_is_ready(spec->port)) {
			LOG_ERR("SensorsMatrix::initialize() Error: %s device is not ready", spec->port->name);
			return -1;
		}

		ret = gpio_pin_configure_dt(spec, GPIO_OUTPUT);
		if (ret != 0) {
			LOG_ERR("SensorsMatrix::initialize() Error: failed to configure %s", spec->port->name);
			return -1;
		}

		LOG_DBG("Configuted port %s pin %d as GPIO_OUTPUT", spec->port->name, spec->pin);

		gpio_pin_set(spec->port, spec->pin, 0);
	}


	if (!device_is_ready(enable_gpios->port)) {
		LOG_ERR("SensorsMatrix::initialize() Error: %s device is not ready", enable_gpios->port->name);
		return -1;
	}

	ret = gpio_pin_configure_dt(enable_gpios, GPIO_OUTPUT);
	if (ret != 0) {
		LOG_ERR("SensorsMatrix::initialize() Error: failed to configure %s", enable_gpios->port->name);
		return -1;
	}

	gpio_pin_set(enable_gpios->port, enable_gpios->pin, 0); // 0 to enable
								//
	LOG_INF ("SensorsMatrix::initialize() Initialized Sensors Matrix...OK Histeresis(%dG-%dG (%dmV-%dmV))", (int32_t)CONFIG_DETECTION_HISTERESYS_EMPTY, (int32_t)CONFIG_DETECTION_HISTERESYS_PIECE, histeresys_empty_mv, histeresys_piece_mv);

	return 0;
}

int SensorsMatrix::calibrate() {
	ScopedLock sl(&calib_mutex);

	//LOG_INF ("Waitting 5s");
	//k_msleep(5000);

	LOG_INF("SensorsMatrix::calibrate() Calculating calibrations...");
	
	for (int k = 0; k < BUFFER_SIZE; k++) {
		readVoltages();
	}

	for (int i = 0; i<8; i++) {
		for (int j=0; j<8; j++) {
			int32_t sum = 0;

			for (int k = 0; k < BUFFER_SIZE; k++) {
				sum = sum + voltages[k][i][j];
			}
			calibrations[i][j] = sum / BUFFER_SIZE;

			if (calibrations[i][j] < 1500 || calibrations[i][j] > 1750) {
				LOG_ERR("calibrations[%d][%d]=%d looks out of range[%d,%d]", i, j, calibrations[i][j], 1500, 1750);
			}

		}
	}

	LOG_INF ("SensorsMatrix::calibrate() Ended calibrations calculation.");
	return 0;
}

bool SensorsMatrix::refresh()
{
	ScopedLock sl(&calib_mutex); // in case of calibrating, this needs to wait

	bool changed = false;

	readVoltages();

	for (int i = 0; i<8; i++) {
		for (int j=0; j<8; j++) {
			bool allGreaterThanHighLimit = true;
			bool allLowerThanLowLimit = true;
			int32_t signOfAll = 0;

			for (int k = 0; k < BUFFER_SIZE; k++) {
				const int32_t signedCalibratedVoltage = voltages[k][i][j] - calibrations[i][j];
				const int32_t calibratedVoltage = signedCalibratedVoltage<0? -signedCalibratedVoltage: signedCalibratedVoltage;
				signOfAll = signedCalibratedVoltage;
				if (calibratedVoltage < histeresys_piece_mv ) allGreaterThanHighLimit = false;
				if (calibratedVoltage > histeresys_empty_mv ) allLowerThanLowLimit = false;
			}

			{
				ScopedLock sl(&my_mutex);
				if ( currentPosition[i][j] != 0 && allLowerThanLowLimit) {
					changed = true;
					currentPosition[i][j] = 0;
				} else if ( currentPosition[i][j] == 0 && allGreaterThanHighLimit) {
					changed = true;
					currentPosition[i][j] = (signOfAll > 0)? 1 : 2;
				}
			}
		}	
	}

	return changed;
}

void SensorsMatrix::getPosition(uint8_t aMatrix[8][8])
{
	ScopedLock sl(&my_mutex);

	memcpy (aMatrix, currentPosition, sizeof(currentPosition));
}

//////////////////////////////////////////////

void SensorsMatrix::getCalibrations(int32_t cals[8][8]) {
	ScopedLock sl(&calib_mutex);
	
	memcpy(cals, calibrations, sizeof(calibrations));
}

void SensorsMatrix::setCalibrations(int32_t cals[8][8]) {
	ScopedLock sl(&calib_mutex);

	memcpy(calibrations, cals, sizeof(calibrations));
}

char * SensorsMatrix::formatCalibrations() {
	return formatVoltagesMatrix(calibrations);
}

char * SensorsMatrix::formatVoltages() {
	return formatVoltagesMatrix(voltages[current]);
}
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

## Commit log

2024-08-13 tentative test of wifi with arduino...
2024-08-17 debug is working. led blinks and breakpoints work
2024-08-22 drawing rpi pico w
2024-08-24 adding rpi pico w board
2024-09-14 uart shell and console working at last!
2025-06-15 compiling for arduino. ignoring wifi features
2025-06-16 basic example of threads, logging and led working on both arduino and nucleo_g474re
2025-06-18 reading 4 adcs and configuring mux gpios. not tested..
    Ready to read board?
2025-06-19 reading all sensors...
2025-06-20 reading sensors, converting to gauss and filtering to get occupancy
2025-06-25 reading the sensors matrix
2025-06-25 adding uart3 and more fine tunning
2025-06-25 enabled second uart to send board position
2025-06-26 sending positions to uart in a separate thread
2025-06-26 use chess python to show the board
2025-06-26 python works and shows the board!!
2025-06-27 changed a couple of things related to filtering and trasposing matrixes
2025-07-10 lichess connector works
2025-07-11 gameplay logic. only pending final adjustments to BoardSerial
2025-07-13 print improvements
2025-07-19 can get voltage and gauss from shell
2025-07-21 flash calibratons logic, not tested
2025-07-23 calibration warning
2025-07-23 fixed the 0s not working and calibrations problem
    [SensorsMatrix.cpp, main.cpp, utils.cpp]
2025-09-22 supporting custom chessbrain board
2025-09-29 initialize 3v3 pin to enabled on boot
2025-10-02 sending uart output to ESP which bridges it to USB
2025-10-04 board inversion ability, ready to play with board upside down (#10)
2025-10-05 improving calibrations (#13)
    * improving calibrations
    waitting correct time after mux changes
    fine tuning histeresis...
    * print gausses matrix command useful for debugging
    * increase mux wait since change from black to white in consecutive squares are affected with 3ms
    [SensorsMatrix.cpp, main.cpp, utils.cpp]
2025-10-05 minimum histeresis because of so good calibrations
2025-10-06 using orange led to see when a movement has been detected. better said when there is uart communication
2025-10-06 uart usb ble bridge
2025-10-07 improving esp32 uart-usb-bluetooth bridge
2025-10-12 improving move detection (#18)
    * 1. opponent's piece can be taken before player's in case of capture
    2. improved messages, more clear
    3. fixed a bug after recovering from wrong position, current_position was not updated
    4. synchronizing tells wrong squares
    5. unwanted data in serial is discarted automatically
    * fixed serial input unwanted
    * when update from board is not received, all squares are considered wrong
2025-10-14 resending last message if receiving REQUEST:1 (#21)
    * resending last message if receiving REQUEST:1
    * sending request:1 te receive current position of board
2025-10-21 First UI (#27)
    * ui examples. choosing kivy
    * adding kivy to requerminets
    * build android app with kivy
    * calculadora example
    * main traces to see if bind succeeded
    * state library and example of workflow
    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
2025-10-24 UI delivery2 (#31)
    * adding wait screen
    * separated config screen
    * adding new screen for game creation. still useless
    * create game binds cancel
    * improving create game screen so much
    * sending game creation data to game logic. ready to talk to lichess api and create real game!!
    * challenges creation work ok against stockfish
    * all types of game can be created
    * handle end of game. no button to return to menu yet
    * fixing rated
2025-11-02 mcuboot + app + upgrader partitions (#48)
    * first try not working
    * working signed fw with mcuboot. problem: 95% of partition used....
    * reducing flash usage to 88%...
    * versioning
    * Add MCUboot as submodule
    * removing files
    * mcuboot integration and buildall script
    * do not modify mcuboot, pass a param instead
    * fine tuning
    * mcumgr compiled not tested
    * configuring updater mode
    * adding upgrader app
    * overlays and device tree tunned
    * update simulation compiles...
    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
    [Led.cpp, SensorsMatrix.cpp, UartSender.cpp]
2026-09-29 kicad projects not yet configured
    [2129691-2.step, B2B-PH-K-S_LF__SN_.step, B7B-ZR_LF__SN_.step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]
2026-09-30 cubeide and new board with all electronics
    [FULL_BOARD_SQ5-B_Cu.gbr, FULL_BOARD_SQ5-B_Mask.gbr, FULL_BOARD_SQ5-B_Paste.gbr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]
2026-09-30 fix typo
    [FULL_BOARD_SQ5.kicad_sch, sensor_matrix.kicad_sch]
2026-09-30 saving work
    [FULL_BOARD_SQ5.kicad_pcb, FULL_BOARD_SQ5.kicad_sch]
2026-10-02 all footprints and started pcb
    [FULL_BOARD_SQ5.kicad_pcb, sensor_matrix.kicad_sch]
2026-10-04 all sensors placed and first connections
    [FULL_BOARD_SQ5.kicad_pcb, FULL_BOARD_SQ5.kicad_sch, sensor_matrix.kicad_sch]
2026-10-05 some configs
    [FULL_BOARD_SQ5.kicad_pcb, FULL_BOARD_SQ5.kicad_sch]
2026-10-08 new sensors matrix board
    [FULL_BOARD_SQ5.kicad_pcb, FULL_BOARD_SQ5.kicad_sch, SENSORS_MATRIX_5CM.kicad_pcb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]
2026-10-10 sensors board almost finished
    [SENSORS_MATRIX_5CM.kicad_pcb, SENSORS_MATRIX_5CM.kicad_sch, sensor_matrix.kicad_sch]
2026-10-15 hw revisions and versions in schematic and pins
2026-10-17 sensors matrix with jlcpcb
2026-10-17 two rows per board, to compare prices
2026-10-17 finishing 2row 5cm pcb
2026-10-24 interconnect 5cm finished. brain v2 with changes pending
